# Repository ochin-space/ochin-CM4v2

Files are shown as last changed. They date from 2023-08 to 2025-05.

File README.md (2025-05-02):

ochin_CM4
# ochin_CM4 v2.0.1
The öchìn CM4 it’s a tiny carrier board for the Raspberry Pi Compute Module  It is designed for applications where a powerful machine with low consumption and small dimensions is required. The small form factor makes it interesting for all those applications where the space available is not much and containing the weight is important, such as in robotics, home automation and IOT.

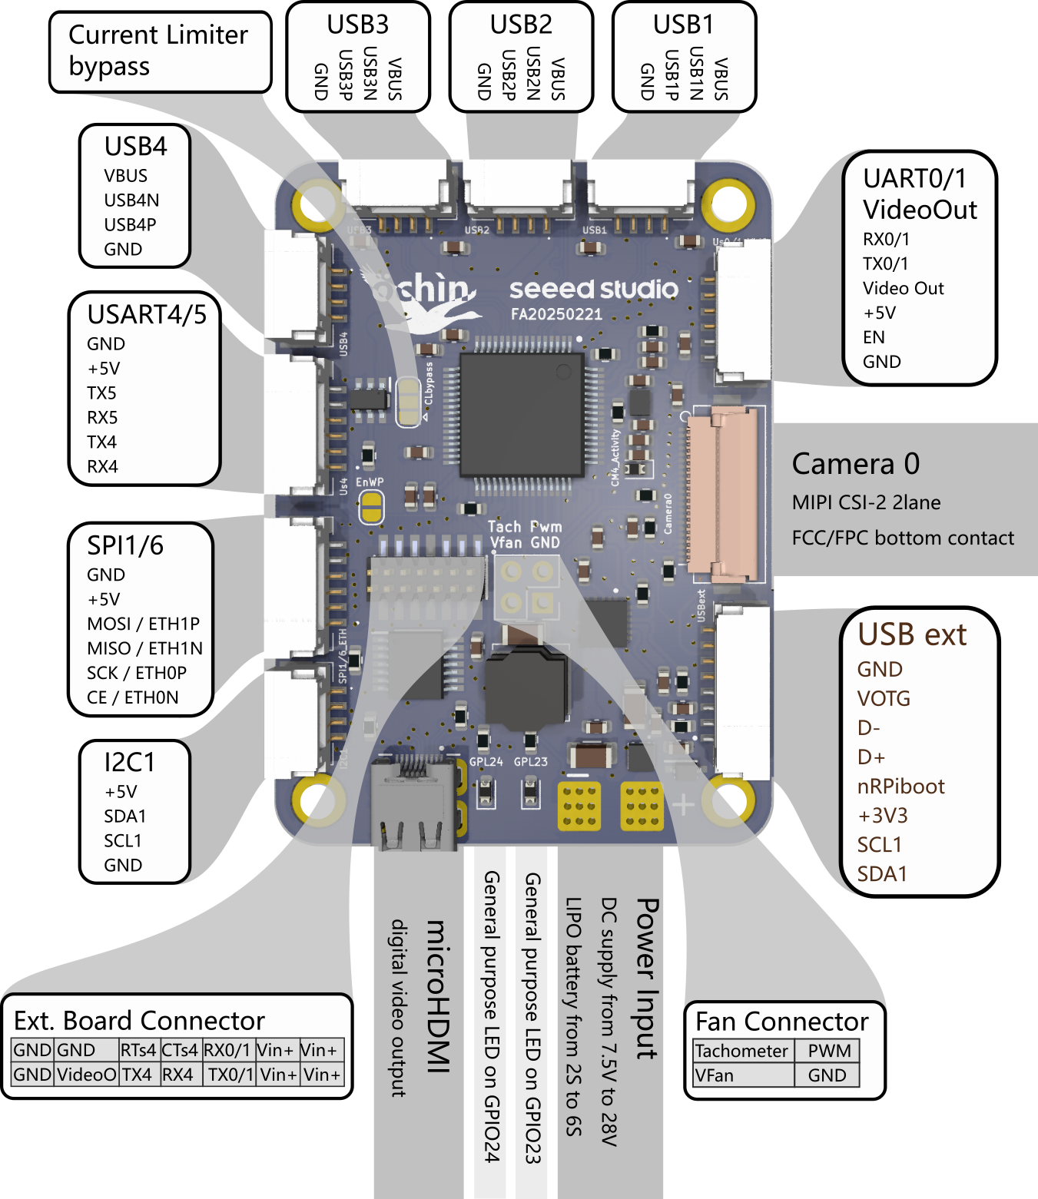
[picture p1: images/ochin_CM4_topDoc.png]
ochin_CM4


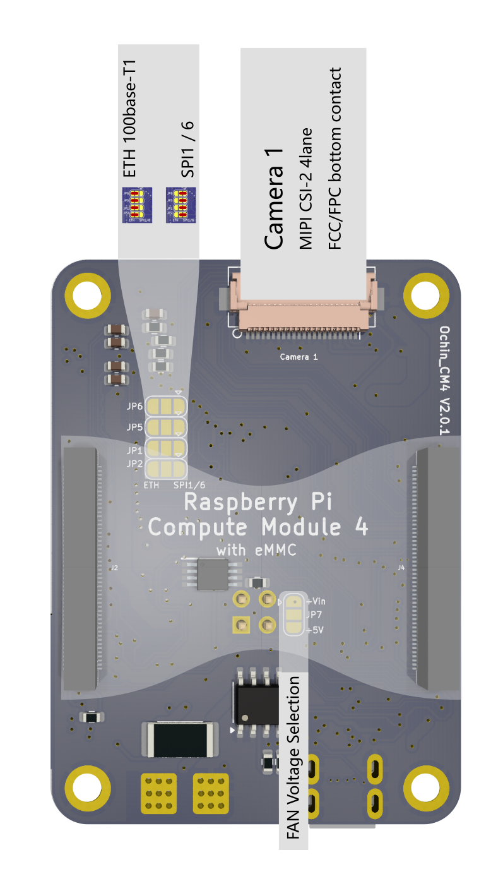
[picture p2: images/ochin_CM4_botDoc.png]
ochin_CM4 back


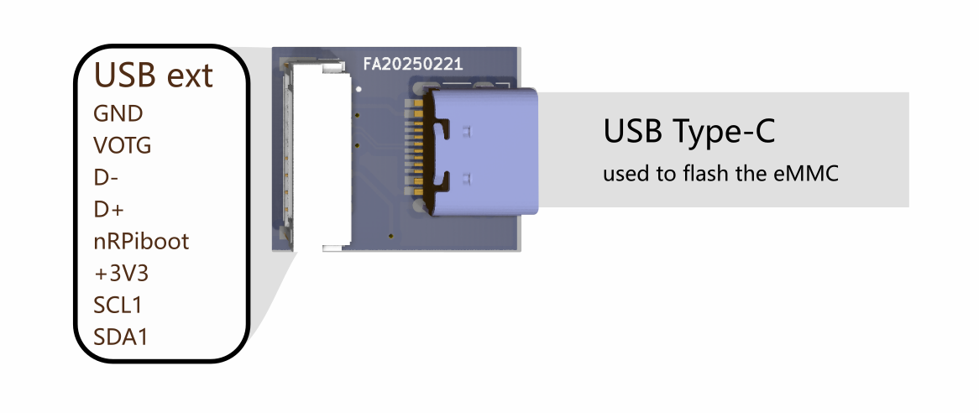
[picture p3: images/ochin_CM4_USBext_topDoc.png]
ochin_CM4extUSB


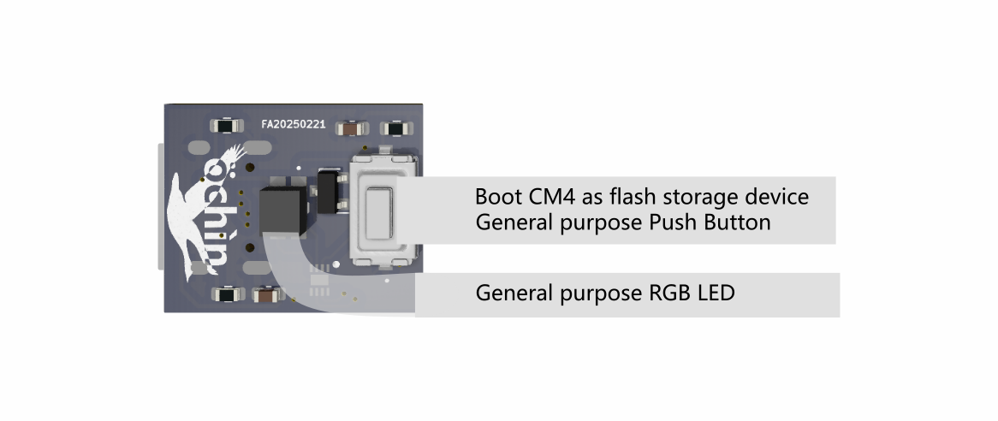
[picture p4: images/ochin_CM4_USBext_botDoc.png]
ochin_CM4extUSB


The board is compatible with all Raspberry Pi CM4 modules equipped with eMMC. Depending on your needs, you can select a CM4 module with an SDRAM starting from 1GB up to 8GB and the eMMC from 8GB up to 32GB, with or without the Wi-Fi/BT module.

Key features of the Raspberry Pi CM4 available on öchìn are as follows:
* Broadcom BCM2711, Quad core Cortex-A72 (ARM v8) 64-bit SoC @ 1.5GHz
* Small Footprint 55mm × 40mm × 4.7mm module
* H.265 (HEVC) (up to 4Kp60 decode), H.264 (up to 1080p60 decode, 1080p30 encode)
* OpenGL ES 3.0 graphics
* Options for 1GB, 2GB, 4GB or 8GB LPDDR4-3200 SDRAM with ECC
* Options for 8GB, 16GB, or 32GB eMMC Flash
o Peak eMMC bandwidth 100MBytes/s
o 2.4 GHz, 5.0 GHz IEEE 802.11 b/g/n/ac wireless
o Bluetooth 5.0, BLE
o On board electronic switch to select between PCB trace or external antenna
* 1×USB 2.0 port (highspeed)

The öchìn CM4v2 board provides the following interfaces:

*	4x USB 2.0 480Mbps (4x SM04B-GHS-TB(LF)(SN) connectors)
*	1x USB Type-C (for flashing eMMC)
*	2x CSI camera (2x FH12-22S-0.5SH (55) connectors)
*	I2C1 (SM04B-GHS-TB(LF)(SN) connector)
*	SPI1 / 6 (SM06B-GHS-TB(LF)(SN) connector)
*	UART0 / 1 + Video Out (SM06B-GHS-TB(LF)(SN) connector)
*	UART4 / UART5 (SM06B-GHS-TB(LF)(SN) connector)
*	1x Ethernet transformerless 100Base-T
*	1x microHDMI
*	2x general purpose LEDs
*	1x RGB LED on external tiny board
*	1x general purpose button on external tiny board

The ochin_CM4v2 card introduces several new features compared to v1, some of which are very interesting and which considerably broaden its range of use. 

Below is a table in which it is possible to see which are the new fetures and which has been removed.

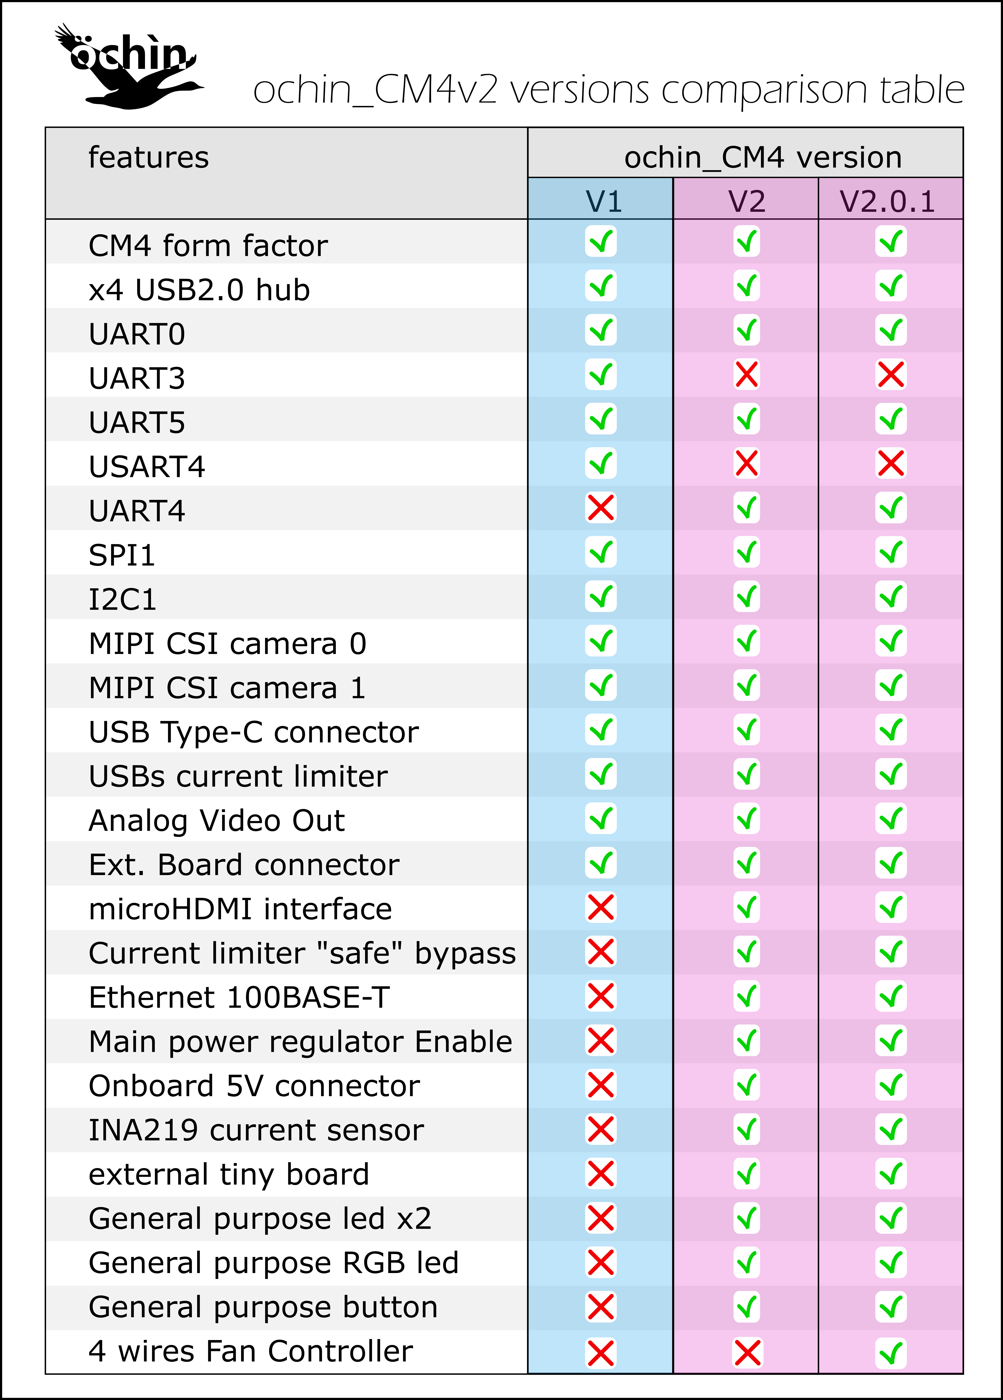
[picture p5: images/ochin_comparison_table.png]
ochin_CM4 comparison table


In this repository you can find the [manual](öchìnCM4v2-Manual.pdf) of the board, a quick start guide for flashing the CM4 module and a guide with some tips on how to make the connections to the ochin board. 

It is important to read them both before turning on the ochin_CM4v2 board, to know its characteristics and above all the sequence in which the signals are present on the connectors.

# Where to buy the ochin_CM4 boards
The ochin_CM4 boards are manufactured and sold by Seeedstudio. You can purchase ochin_CM4 boards from Seeedstudio's marketplace, https://www.seeedstudio.com or from Seeedstudio's business partners (Digikey, Mouser, RS components and many others).

# License Notice for This GitHub Repository

This GitHub repository contains various resources that are subject to specific licenses. Please note the following information regarding the applicable licenses:

* Documentation, Manuals, PDF Schematics, scripts and Other Textual Content: All textual documents present in this repository, including manuals, schematics, and documentation, are released under the GNU Free Documentation License (GFDL).

* Hardware (KiCad Sources, Gerber Files, Assembly Files, etc.): The hardware-related items, including but not limited to KiCad sources, Gerber files, and assembly files, are subject to a proprietary license. This means that these resources are not released as open source and their use is governed by the terms specified in the accompanying documentation or separate terms of use provided.

Please respect the conditions of both licenses when using and distributing the materials in this repository.

For any questions or clarifications regarding the [LICENSE](LICENSE), feel free to contact us.

# Important!!!

Print and use the extractor for the CM4 module if you don't want to break the mezzanines, you can find the [ochin_mount-extractor.stl](3d/CoversTurretsAndExtractors/ochin_mount-extractor.stl) in the "3d/CoversTurretsAndExtractors" section of this repository.

Take a look at the [öchìnCM4v2-WiringAndSuggestions.pdf](öchìnCM4v2-WiringAndSuggestions.pdf) before power the board on, it may save your time and your devices.

Never trust the color code of the GHS cables, the sequence in which commercial GHS cables are assembled is often random and does not reflect the sequence of the signals present in the connectors of the ochin_CM4 board.

Please refer to the file [öchìnCM4v2-HW-bugs.pdf](öchìnCM4v2-HW-bugs.pdf) for details regarding known issues on the board and the respective version in which they were resolved

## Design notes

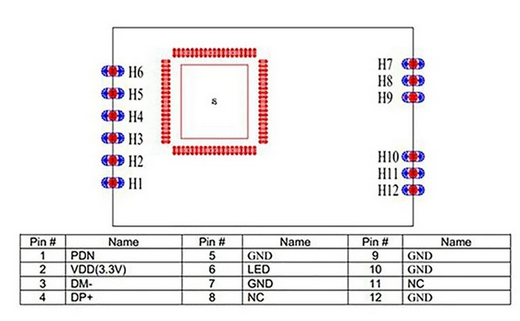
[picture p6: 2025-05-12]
3d/ochin VRX goggleBox/kicad RTL8812AU module pwr/RTL8812AU_pinout.png

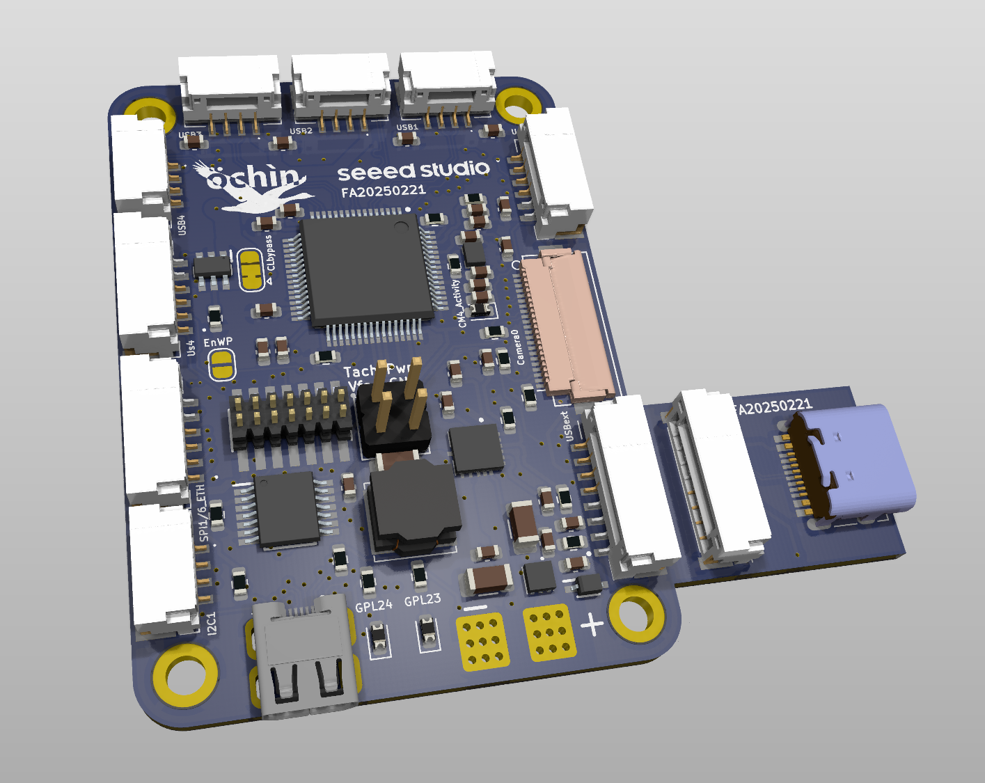
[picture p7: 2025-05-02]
images/Ochin_CM4_main_top_back.png

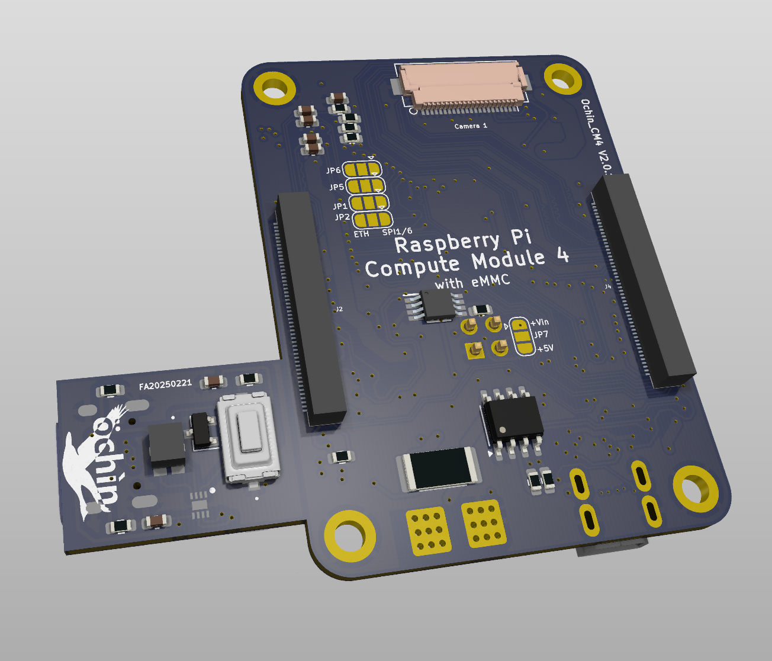
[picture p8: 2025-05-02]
images/Ochin_CM4_main_bot.png

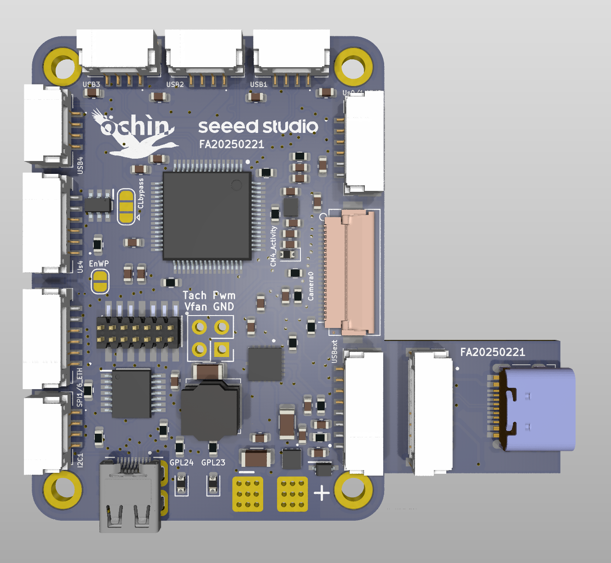
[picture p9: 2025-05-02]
images/Ochin_CM4_top_main.png

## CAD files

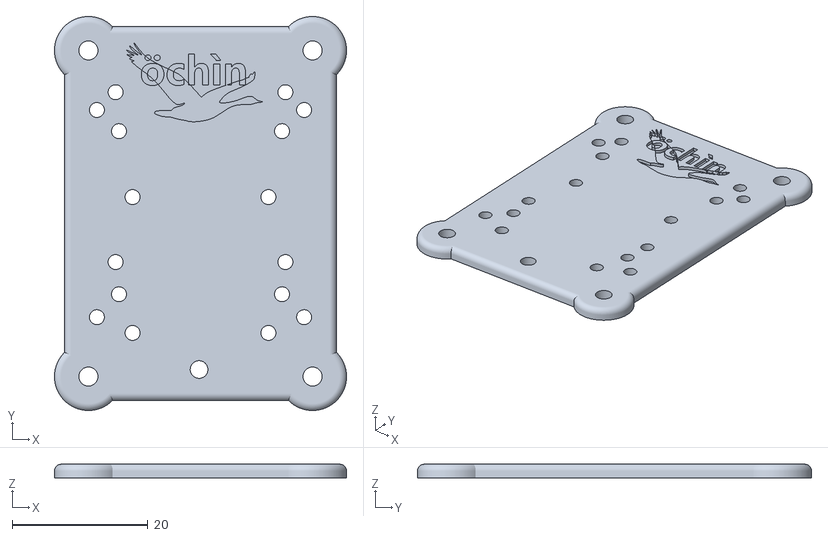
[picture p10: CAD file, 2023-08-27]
3d/CoversTurretsAndExtractors/ochin_mount-topCover.stl
43.0 x 58.0 x 2.00

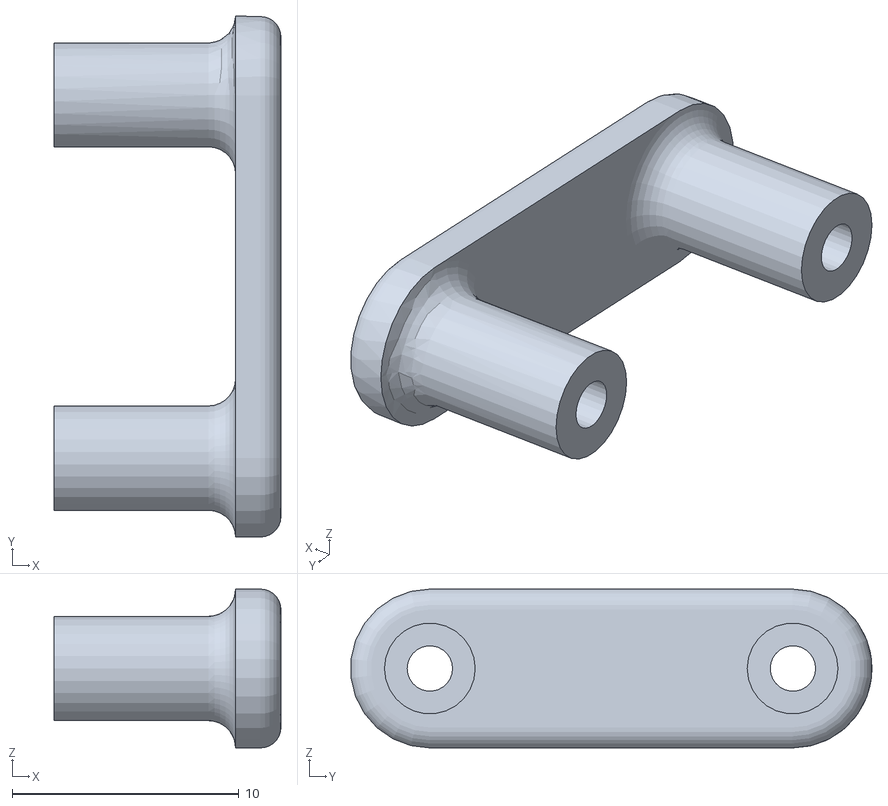
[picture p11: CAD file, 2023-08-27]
3d/EasyStar ii_IMX219_mount/EasyStar_camera_mount_bridge.stl
10.0 x 23.0 x 7.00

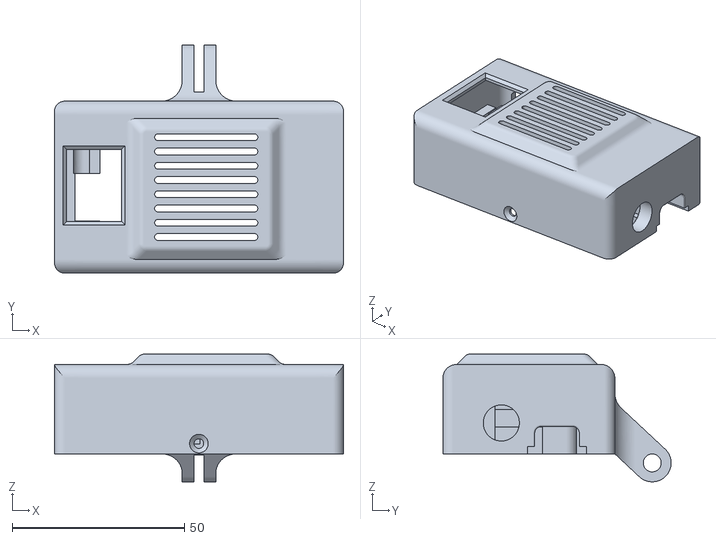
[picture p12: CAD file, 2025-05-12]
3d/ochin VRX goggleBox/Top.stl
84.0 x 66.4 x 37.1

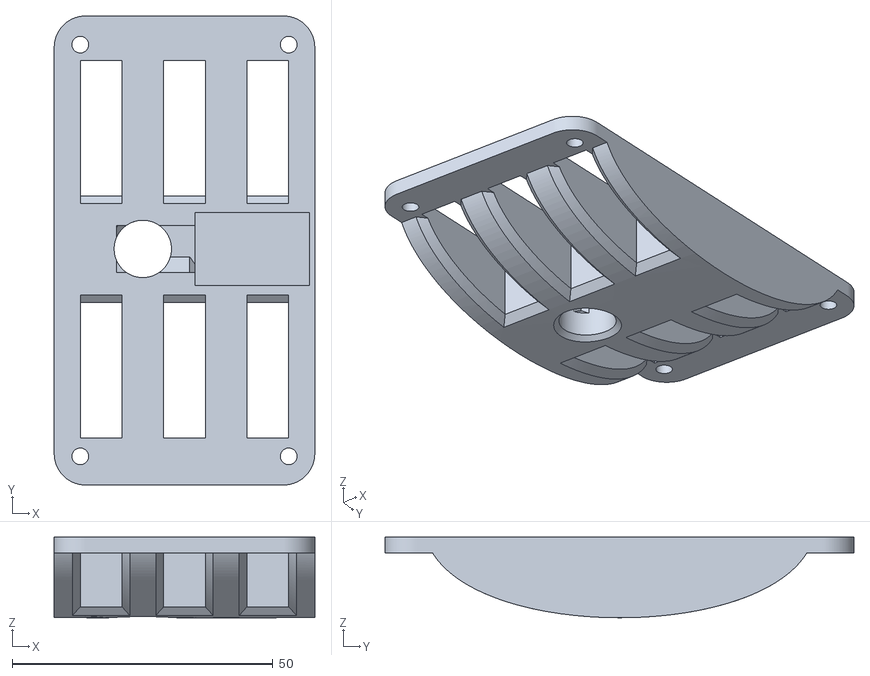
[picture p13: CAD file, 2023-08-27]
3d/ochin_cm4_plate_mount/ochin_cover+camera.stl
50.0 x 90.0 x 15.5

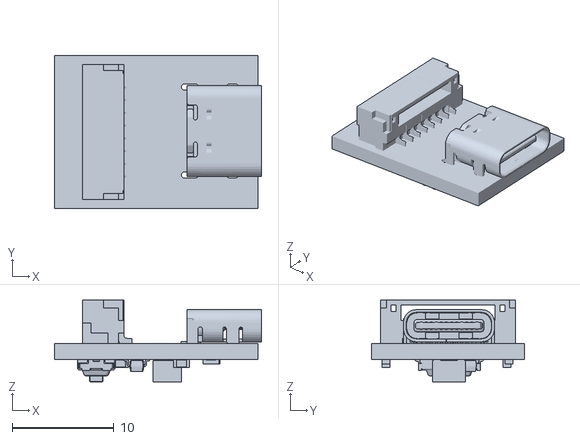
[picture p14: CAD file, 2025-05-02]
3d/ochin_CM4v2_0_1/Ochin_CM4_V2_0_1_ext.stl
20.3 x 15.0 x 8.04

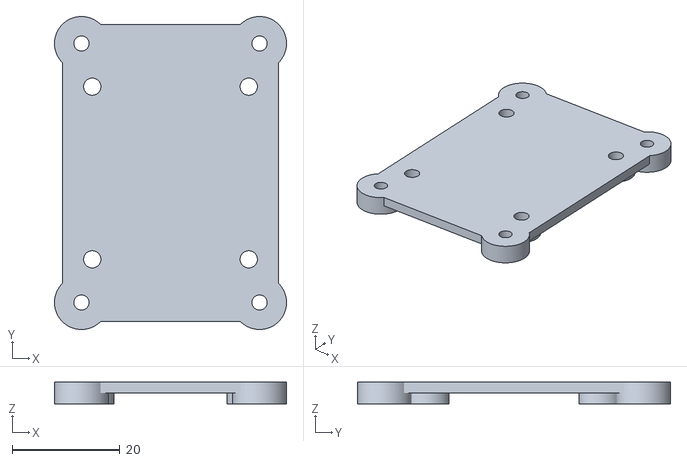
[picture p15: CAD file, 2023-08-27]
3d/CoversTurretsAndExtractors/ochin_mount-botCover.stl
43.0 x 58.0 x 4.00

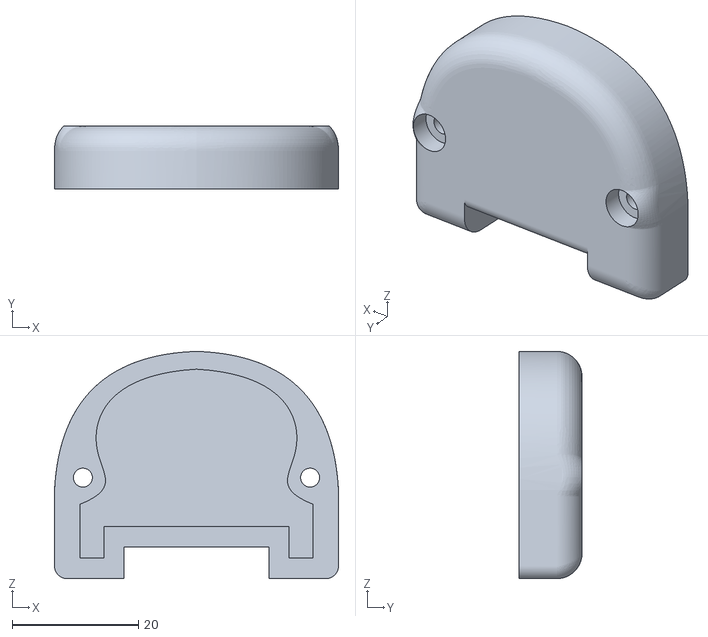
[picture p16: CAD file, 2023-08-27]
3d/EasyStar ii_IMX219_mount/EasyStar_camera_mount_cap.stl
45.0 x 10.0 x 36.0

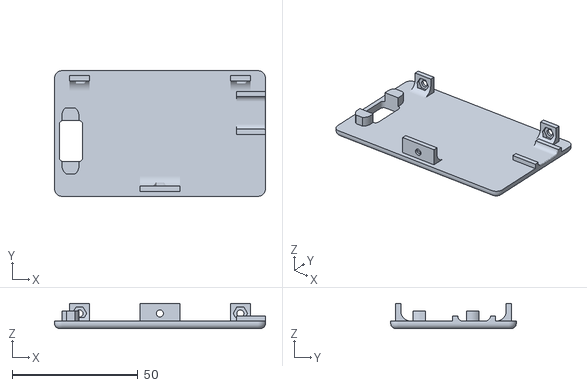
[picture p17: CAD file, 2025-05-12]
3d/ochin VRX goggleBox/Bot.stl
84.0 x 50.0 x 10.0

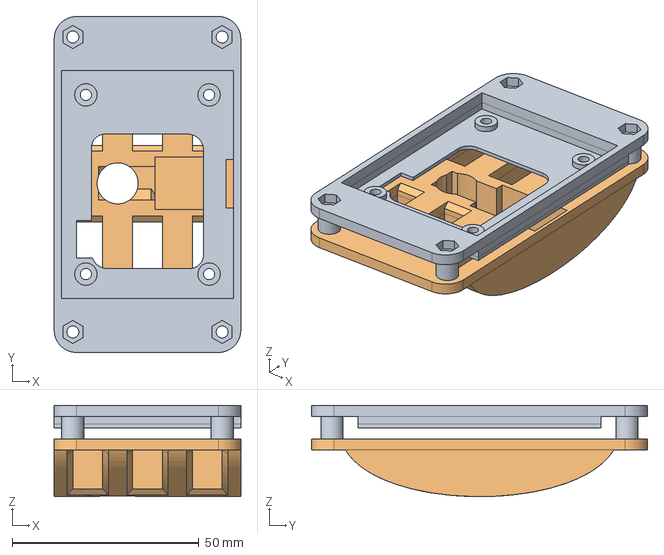
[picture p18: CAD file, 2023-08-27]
3d/ochin_cm4_plate_mount/ochin_plate+cover.FCStd
50.0 x 90.0 x 24.5 mm
ochin mount
cover+camera

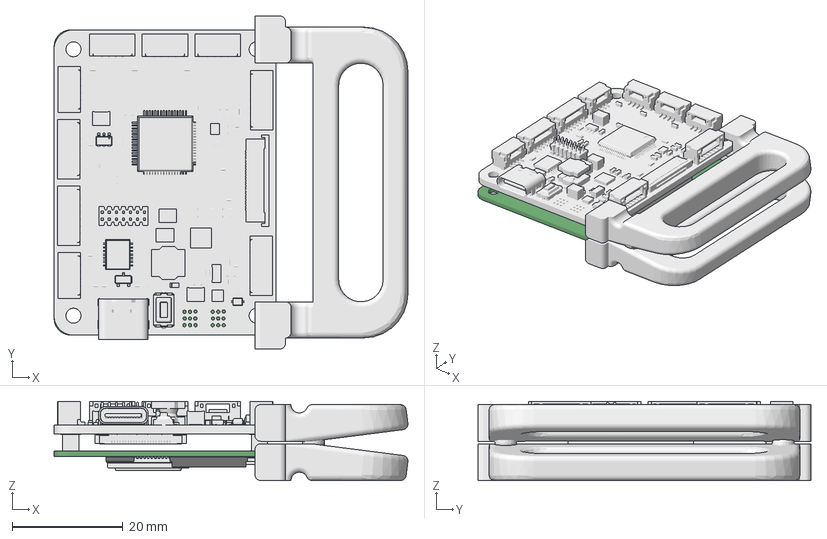
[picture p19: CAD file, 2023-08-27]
3d/CoversTurretsAndExtractors/ochin_mount.FCStd
63.8 x 60.0 x 14.3 mm
PCB
BROADCOM_BCM2711
CONNDF40C-100DP-04V
CONNDF40C-100DP-04V (1)
MAXLINEAR_MXL7704-R
RM0_FOOTPRINT_V2
SAMSUNG_KLM4G1YE4C-B00X
SDRAM-LPDDR4-X32-D2-BGA200
extractor
extractor2
ochin_CM4-Ochin

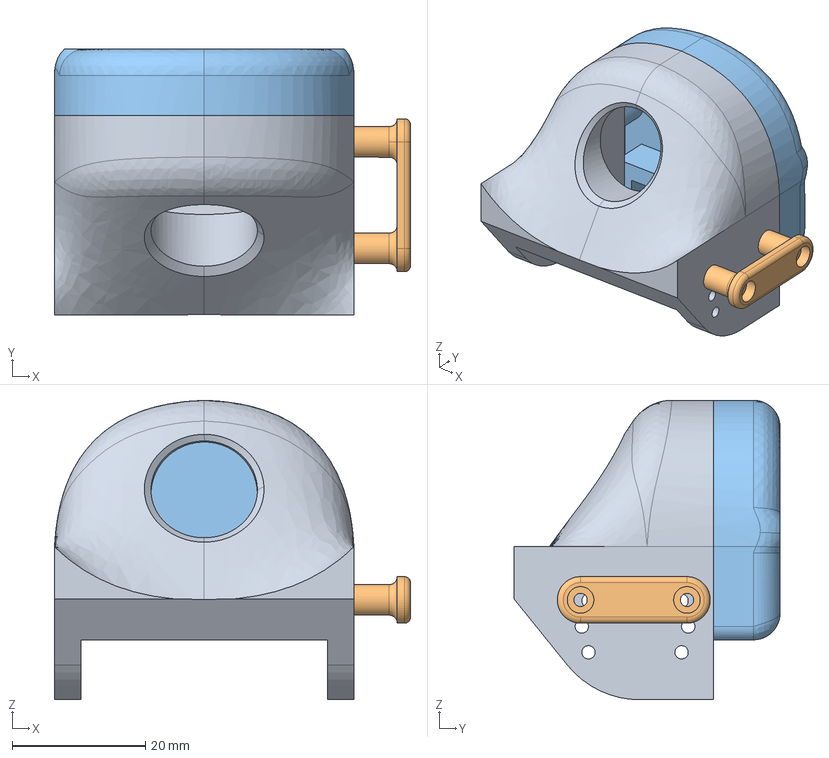
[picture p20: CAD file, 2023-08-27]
3d/EasyStar ii_IMX219_mount/EasyStar_camera_mount.FCStd
53.5 x 40.0 x 45.0 mm
supportoCam
staffa
coperchio

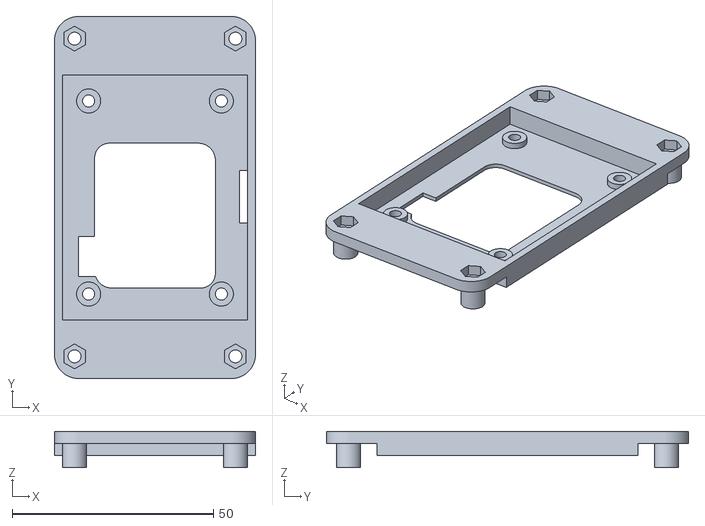
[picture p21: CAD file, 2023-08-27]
3d/ochin_cm4_plate_mount/ochin_plate.stl
50.0 x 90.0 x 9.00

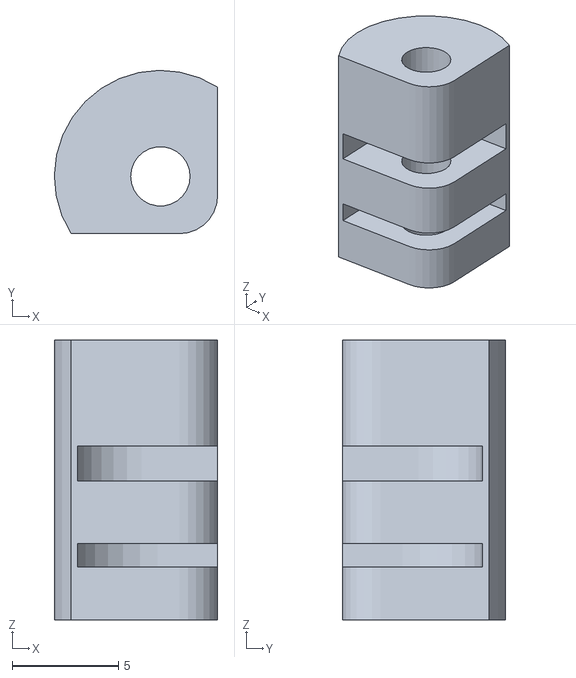
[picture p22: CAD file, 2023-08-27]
3d/CoversTurretsAndExtractors/ochin_mount-turret.stl
7.70 x 7.70 x 13.2

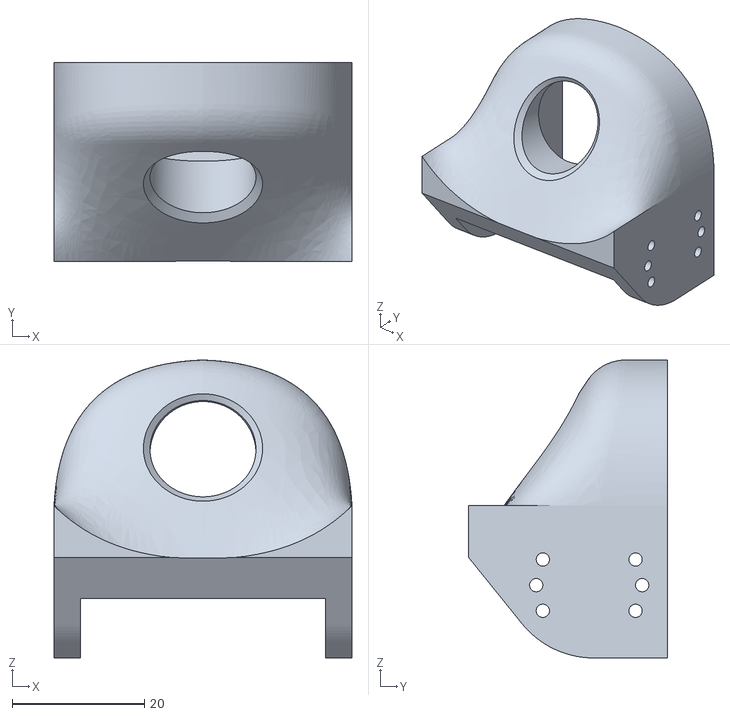
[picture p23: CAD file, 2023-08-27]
3d/EasyStar ii_IMX219_mount/EasyStar_camera_mount_front.stl
45.0 x 30.0 x 45.0

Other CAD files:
3d/CoversTurretsAndExtractors/ochin_mount-extractor.stl
3d/ochin VRX goggleBox/ochin_goggleBox v18.f3d

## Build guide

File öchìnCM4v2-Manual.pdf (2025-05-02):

öchin CM4v2 carrier board manual v0.2 | 9 agosto 2024

## Introduction

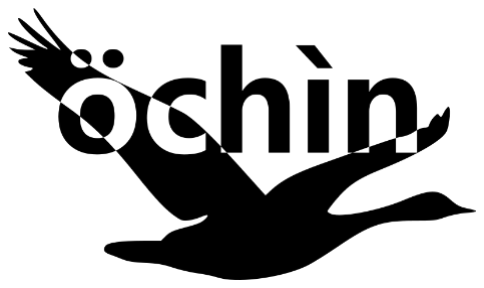
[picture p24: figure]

The öchìn CM4v2 it’s a tiny carrier board for the Raspberry Pi Compute Module 4. It is designed for applications where a powerful machine with low consumption and small dimensions is required. The small form factor makes it interesting for all those applications where the space available is not much and containing the weight is important, such as in robotics, home automation and IOT.

The board is compatible with all Raspberry Pi CM4 modules equipped with eMMC. Depending on your needs, you can select a CM4 module with an SDRAM starting from 1GB up to 8GB and the eMMC from 8GB up to 32GB, with or without the Wi-Fi / BT4 connection.

Key features of the Raspberry Pi CM4 compatible with öchìn are as follows:

- Broadcom BCM2711, Quad core Cortex-A72 (ARM v8) 64-bit SoC @ 1.5GHz
- Small Footprint 55mm × 40mm × 4.7mm module
- H.265 (HEVC) (up to 4Kp60 decode), H.264 (up to 1080p60 decode, 1080p30 encode)
- OpenGL ES 3.0 graphics
- Options for 1GB, 2GB, 4GB or 8GB LPDDR4-3200 SDRAM with ECC
- Options for 8GB, 16GB, or 32GB eMMC Flash
- Peak eMMC bandwidth 100MBytes/s
- 2.4 GHz, 5.0 GHz IEEE 802.11 b/g/n/ac wireless
- Bluetooth 5.0, BLE
- On board electronic switch to select between PCB trace or external antenna
- 1×USB 2.0 port (highspeed)
- MIPI CSI-2:
- 1×2-lane MIPI CSI camera port, 1×4-lane MIPI CSI camera port
- 1×USART, 3×UART, 1×I2C port, 1×SPI port, Analog Video Output

Design

The board has the same dimensions as the RPi CM4 module, 55mm x 40mm with rounded corners.
Several interfaces like USARTs, USBs are addressable bye the SM06B-GHS and SM04B-GHS connectors, available on the sides of the board. Two FCC/FPC connector are available to connect two MIPI CSI-2 cameras. The front camera is the “camera 1” which is a MIPI CSI-2 4lane camera. The side camera is the “camera 0” which is a MIPI CSI-2 2lane camera. The two FCC/FPC connectors have contacts on the bottom, the interface is the same used on the Raspberry Pi Zero.
On top of the board there is a 14x1.27mm connector, that could be used to connect a custom board on top, replacing the top PCB cover.
On the bottom of the öchìn carrier board there are the DF40HC(3.0)-100DS-0.4v mating connectors for the CM4 module.

## Applications

The powerful Quad core Cortex-A72 CPU and GPU, the big RAM size and the CODECs and Graphic Accelerators available on the CM4 makes the system very interesting for a huge number of applications. Are suitable all the applications related to audio / video manipulation and streaming, neural networks, machine learning, computer vision, etc.

There are several communication interfaces available on board that enables to connect the öchìn to external hardware to connect to the lower abstraction layers, closer to the physical world.

An example of use could be a drone, where a flight controller board sense the physical references and control the actuators and motors to guarantee the stability of the flight. It could handle the stability of the vehicle, collect the data from the sensors and from the remote control and send the telemetry data back to the ground station. This is a very common structure nowadays for a UAS. The öchìn board could be used to add a wide range of functionality to the system.

The öchìn could handles up two MIPI cameras and others connected to the USB interfaces. Other sensors could also be added to the öchìn using the UART, SPI, I2C interfaces. All those data could be processed by several threads running on the CM4.

The software infrastructure available within the CM4 enables to code with C/C++, python, MATLAB, and several other languages. There is also a wide number of frameworks that can be used to develop algorithms with Deep Learning, Neural Networks or Computer Vision technique, such as OpenCV, Caffe, PyTorch, TensorFlow etc. The öchìn board also provide the analog video output from the CM4. It means that it’s possible to create a video output from the whole set of data, including images and its elaboration, to transmit like a common analog video out. This is very convenient because it gives the chance to see the output of the processing in real time without taking care of creating a digital wireless bridge.

This is only an example, a similar structure could be though for rovers, submarines, airplanes, and robots in general. Of course, the öchìn board it’s very interesting for the IOT world also, where the size and weight is important. In this scenario, the AI is relevant and the tendency to miniaturize IOT devices and make them increasingly intelligent requires adequate hardware.

## Hardware interfaces

The öchìn CM4v2 board provides the following interfaces on the side’s connectors:

- 4x USB 2.0 480Mbps (4x SM04B-GHS-TB(LF)(SN) connectors)
- 1x USB Type-C (for flashing eMMC)
- 2x CSI camera (2x FH12-22S-0.5SH (55) connectors)
- I2C1 (SM04B-GHS-TB(LF)(SN) connector)
- SPI1 / 6 (SM06B-GHS-TB(LF)(SN) connector)
- UART0 / 1 + Video Out (SM06B-GHS-TB(LF)(SN) connector)
- UART4 / UART5 (SM06B-GHS-TB(LF)(SN) connector)
- 1x Ethernet transformerless 100Base-T
- 1x microHDMI
- 2x general purpose LEDs
- 1x RGB LED on external tiny board
- 1x general purpose button on external tiny board
- 1x 4-Wire Fan controller (pwm, tacho, supply voltage selectable, Vin or 5V)

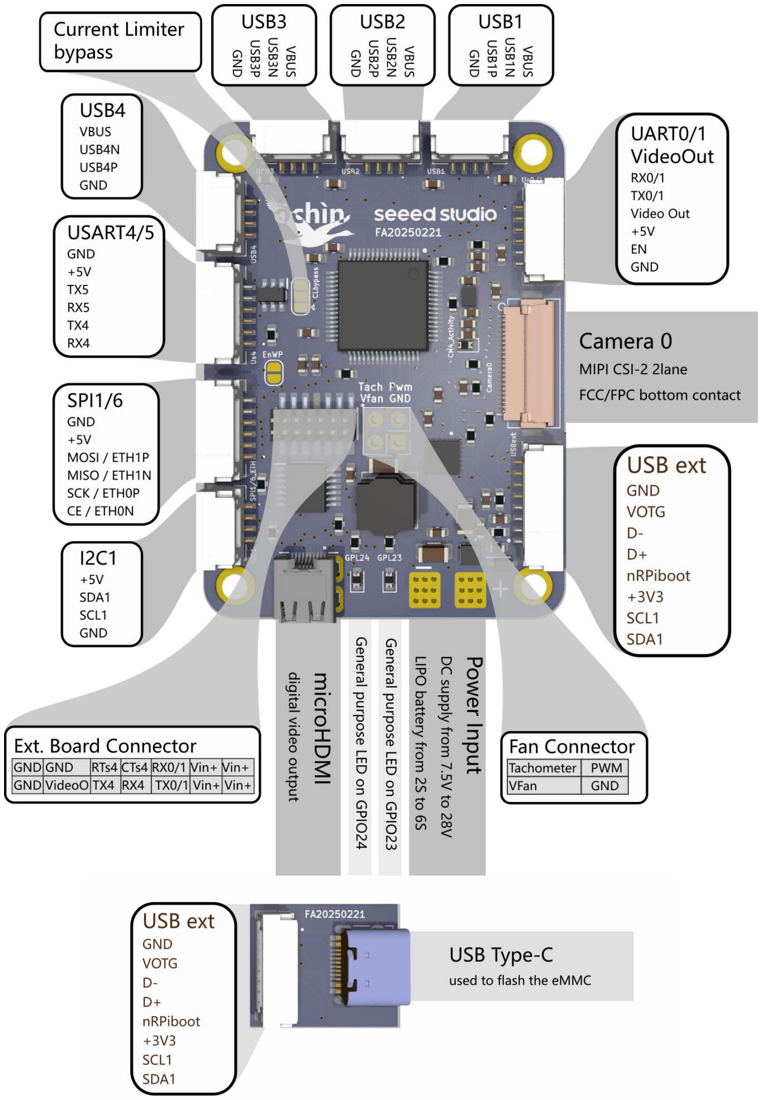
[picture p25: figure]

Top view

Bot view

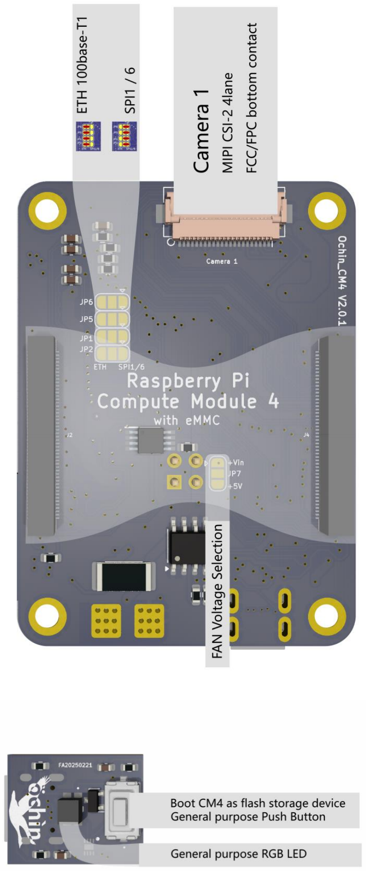
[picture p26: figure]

## USB

The Raspberry Pi CM4 module is equipped with a single USB2.0 interface. In order to connect multiple USB devices to the CM4 module, the ochin_CM4v2 board is equipped with a 4xUSB2.0 HUB. The four USB ports are accessible via the four SM04B-GHS connectors. We recommend that you read the document 'Wiring and Suggestion' to make the connections correctly.

It should be noted that the same USB port on the CM4 is also shared with the USB Type-C connector, which is needed to write the OS in flash. This switching occurs when connecting USB Type-C to a computer. In fact, the VBus provided by the computer switches the USB from the HUB to the Type-C port to allow the module to be flashed.

It is therefore important to bear in mind that none of the 4 USB ports will work as long as the ochin board is connected via a USB Type-C cable to a computer.

## SPI1/Ethernet

The connector, named SPI1/6, can be used to connect to either the SPI1/6 or the Ethernet port. In order to allow either connection, there are four smd switches (normally open) on the back of the ochin_CM4v2 board, which must be soldered appropriately.

In order to use the connector as SPI1/6, it is necessary to solder the jumpers between the central pad and the pad on the right (indicated by the word SPI1/6) of JP6,5,1,2 as shown in the following figure:

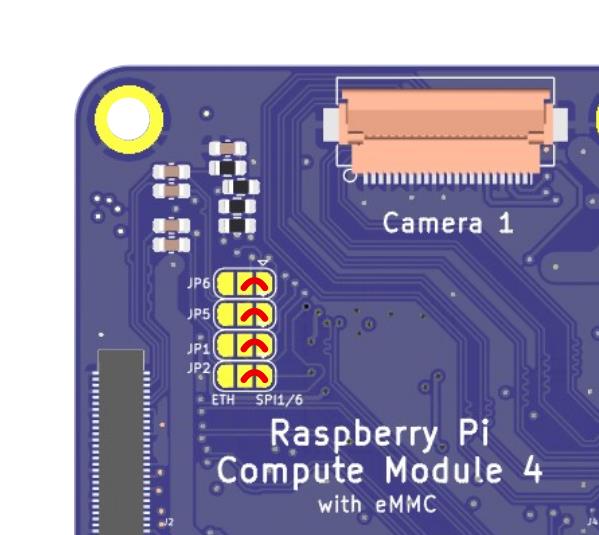
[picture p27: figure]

The order of the signals on the SPI1/6 connector is as follows

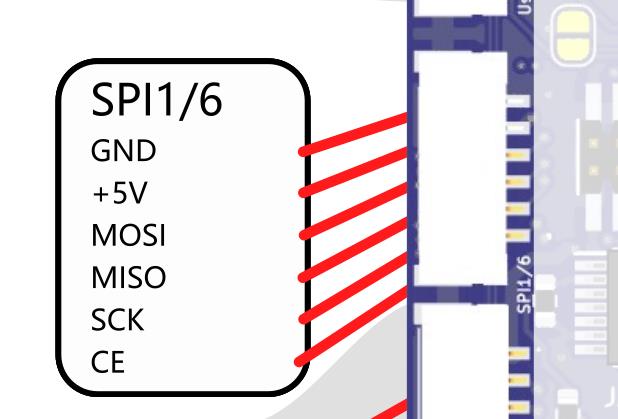
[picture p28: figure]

In the case of connecting to the Ethernet port of the RPI CM4, the smd switches JP6,5,1,2 should be soldered as follows:

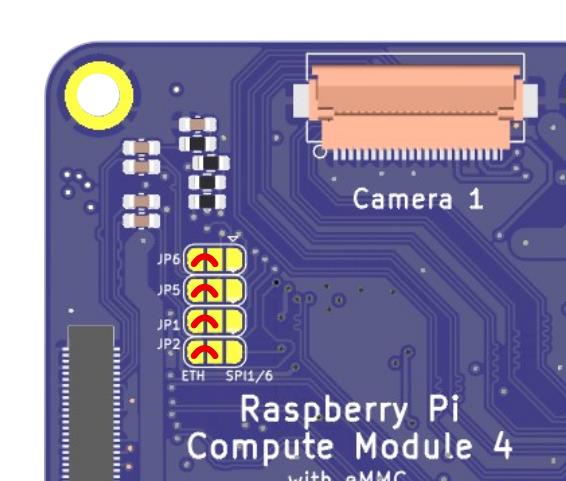
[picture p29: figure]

In this case, the order of the signals on the SPI1/6 connector will be as follows:

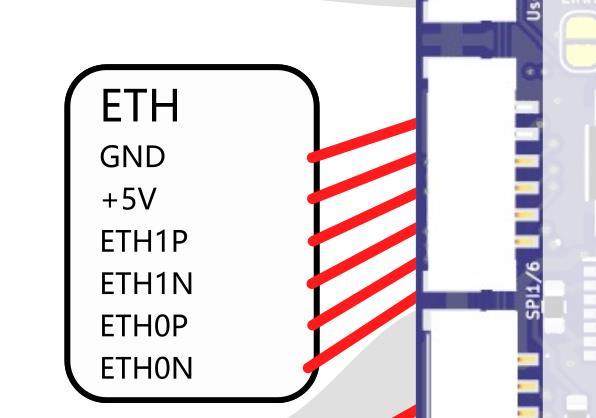
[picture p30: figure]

An important note must be made regarding the Ethernet connection. In order to allow Ethernet connectivity and without affecting the size of the ochin_CM4v2 board, it was decided to adopt a transformerless configuration, like the one adopted and described by Texas Instruments in Application Note AN-1519 for their DP83848 Ethernet devices. It is therefore advisable to study and understand the AP-1519 before deciding to use the Ethernet port in a transformerless configuration.

The following image represents the connection diagram for connecting to the ochin_CM4v2 using a standard RJ45 cable:

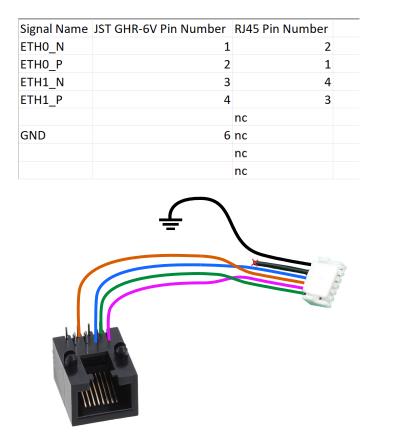
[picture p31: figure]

## The Fan Controller

he Ochin board features an integrated EMC2301 fan controller connected to the I²C1

bus. To support external fans operating at 5V, 12V, or higher voltages, a normally open

SMD switch is provided on the bottom side of the board and must be soldered manually

to enable fan power routing.

By default, if the EMC2301 is not actively configured via software, the fan will operate

at maximum speed. When properly controlled, the EMC2301 allows for PWM-based

speed regulation of both 3-wire (open-loop) and 4-wire (tacho-sensed) fans.

A basic Python test script is included in the documentation to verify functionality. For

accurate integration and usage, please refer to the EMC2301 datasheet.

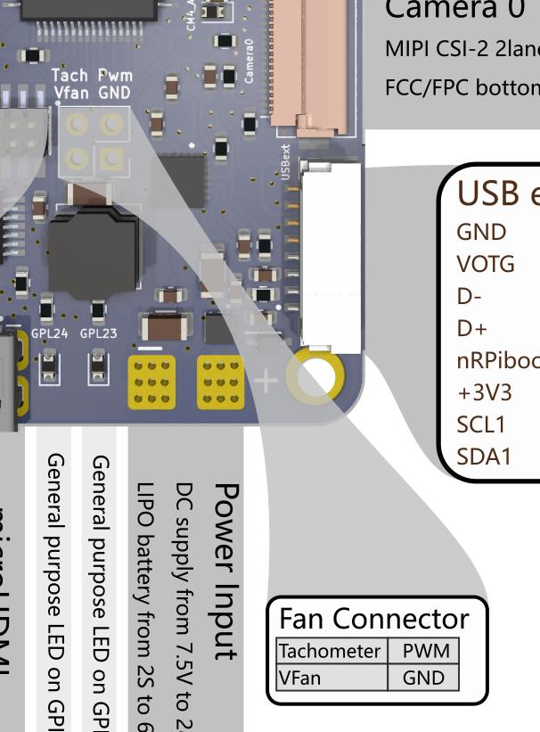
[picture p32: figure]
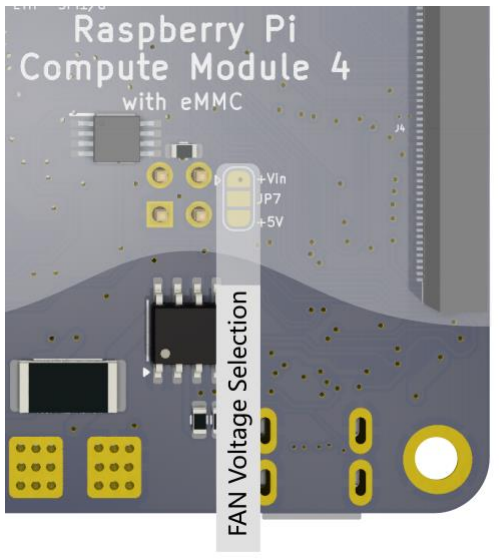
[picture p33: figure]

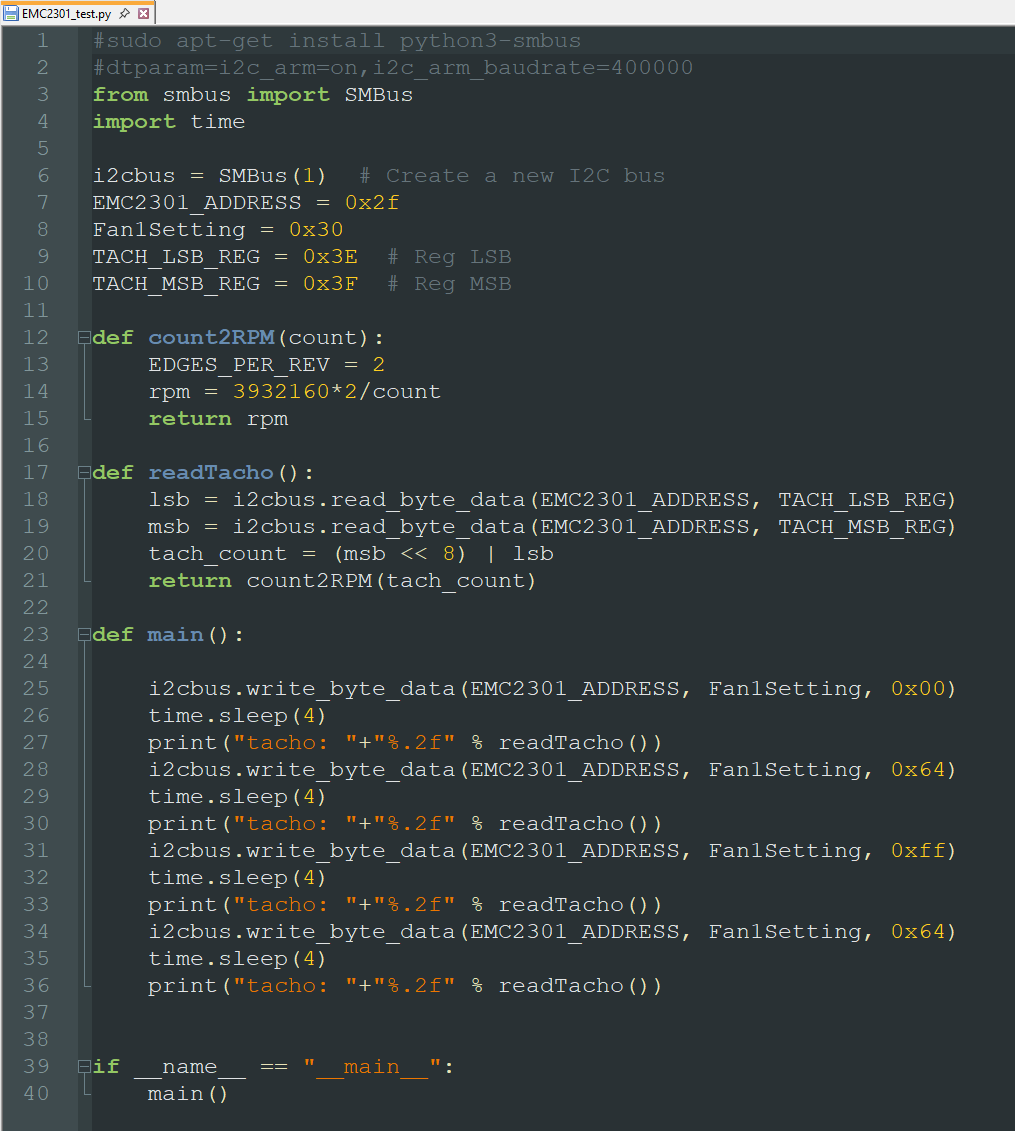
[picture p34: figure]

## The Current Limiter

The IC4 - AP22615AWU-7 is a single-channel current-limited high-side
power switch with output OVP optimized for USB and other hot-swap
applications. On the ochin_CM4 board, the current threshold of the AP22615AWU-7 is set to 3A. If the IC4 it’s triggered, it will cut the VBUS on the USBs to keep the CM4 supplied while an overcurrent condition happens. There are four possible condition that triggers the current limiter:
(from the AP22615 datasheet Document number: DS41022 Rev. 5 – 2):

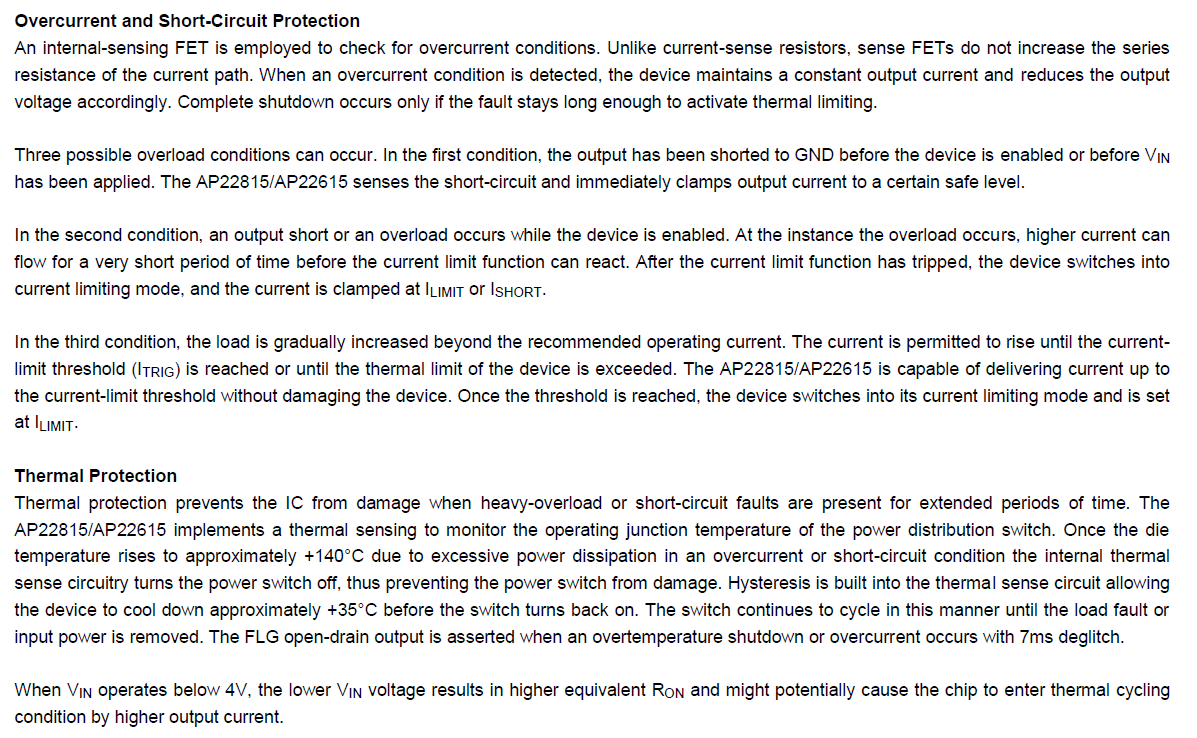
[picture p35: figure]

In case more current is needed on the USBs, it is necessary to short JP4 (CLbypass).

Before shorting JP4, it is important to cut the "normally closed" trace, between pads 1

and 2 of JP4 (pad 1 is the one indicated by the triangular marker). This is done by using

a sharp blade and making sure that you only cut the connection between the two pads,

and if necessary, test it with a multimeter. If the current limiter is bypassed, the USB

power supply is connected directly to the output of the +5V switching regulator, the

same one that powers the CM4. The power supply can provide up to 8A, leaving 2A for

the CM4 (the manual says 1.4A but it is best to be cautious); 6A remains available for

USB and external peripherals. That said, before removing the limiter, it is important to know how much current the external peripherals will draw, so leave current for the CM4,

otherwise it will reboot.

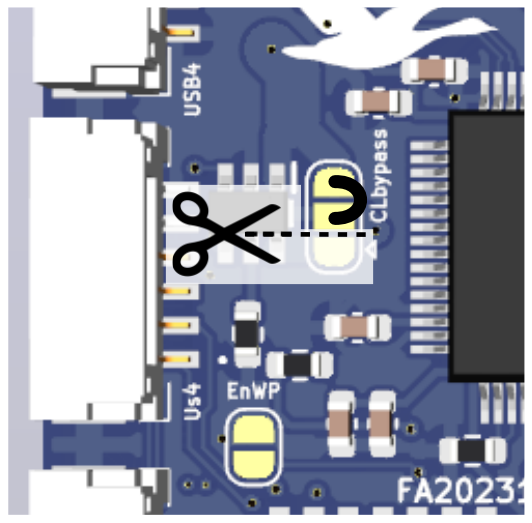
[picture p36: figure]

## eMMC write protection

To write protect the eMMC it’s necessary to short the jumper named EnWp:

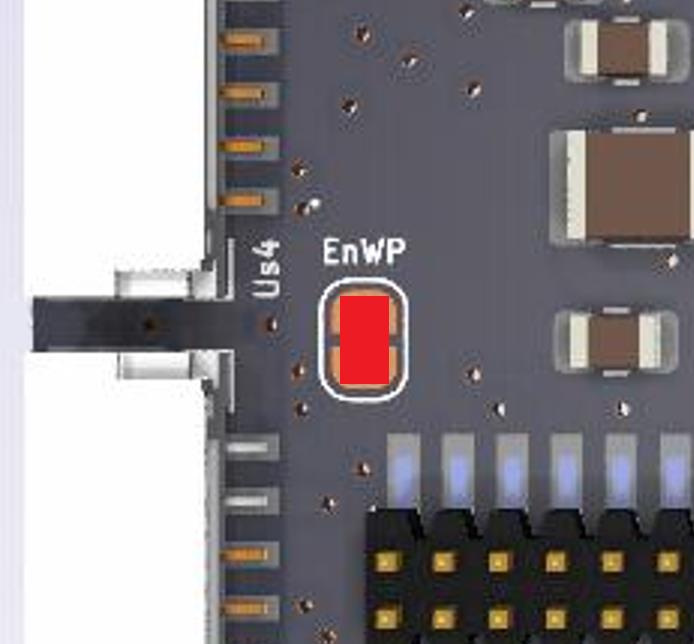
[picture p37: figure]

## The current sensor INA219

In order to measure the current drawn by the ochin_CM4v2 board and all its peripherals, it was equipped with an INA219 current sensor. The chip is located on the bottom of the pcb and works by measuring the potential drop at the ends of a shunt resistor. The chip is connected to the CM4 module via the I2C1 bus (addr. 0x40) by means of which it is possible to read the input voltage measurement, the shunt voltage and after calibration of the chip also power and current drawn. To calculate the current from the shunt voltage, it is necessary to know the shunt resistance, which in the case of the ochin_CM4v2 is 100mOhms. For details on how to read, write and calibrate the INA219 chip, it is necessary to study its datasheet, provided by Texas Instruments.

## The LEDs GPL23 and GPL24

The anodes of the two LEDs GPL23 and GPL24 are connected to the GPIO23 and

GPIO24 pins of the Raspberry Pi CM4, respectively. They can be used for debugging

purposes or for status signalling. It is possible to manage the two LEDs by means of the

Raspberry Pi's GPIO management libraries.

Below is an example of managing the two LEDs using a script in Python:

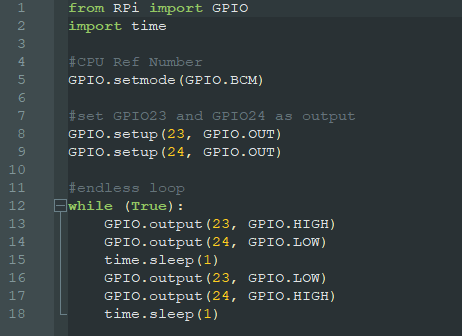
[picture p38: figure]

## The S1 button

The S1 button on the small external board has two functions. The first is to put the

CM4 module in 'flash mode' to allow the user to access the flash on the module itself.

This procedure is explained in more detail in the "Software Configuration" section. If

the CM4 module is started up in normal mode, the S1 button also performs the

function of a "user button". This is possible because in addition to being connected to

the "nRPIBOOT" pin, it is also connected to the GPIO4 pin. The button can therefore

be used during normal operation to interact with the sw running on the CM4 module.

To know the status of the button, i.e. whether it is pressed or not, simply configure the

GPIO4 as an input and monitor its status. Since GPIO4 is "active low", it is to be

expected that it will go to "false" if S1 is pressed and be "true" the rest of the time.

Below is an example of managing the two LEDs using a script in Python:

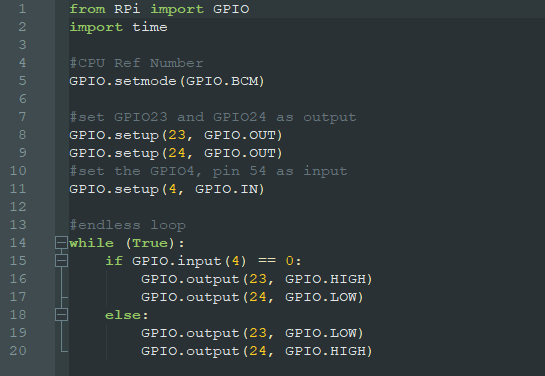
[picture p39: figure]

## The RGB led

On the external board, next to the S1 button is an RGB LED. This LED is present for the

purpose of being used at will by the user, to communicate any information by means of

all possible colour tones, intensities and flashes. Management of the RGB LED is

entrusted to a chip called KTD2026, which is connected to the CM4 module via the I2C1

interface.

Using the I2C libraries, it is possible to configure the chip to vary the intensity of each

of the three basic colours and their respective transitions. For more precise and detailed

information on the handling of the chip, it is necessary to study the datasheet of the

KTD2026, available on the website of the manufacturer, Kinetic Technologies

(https://www.kinet-ic.com).

Below is an example of managing the two LEDs using a script in Python:

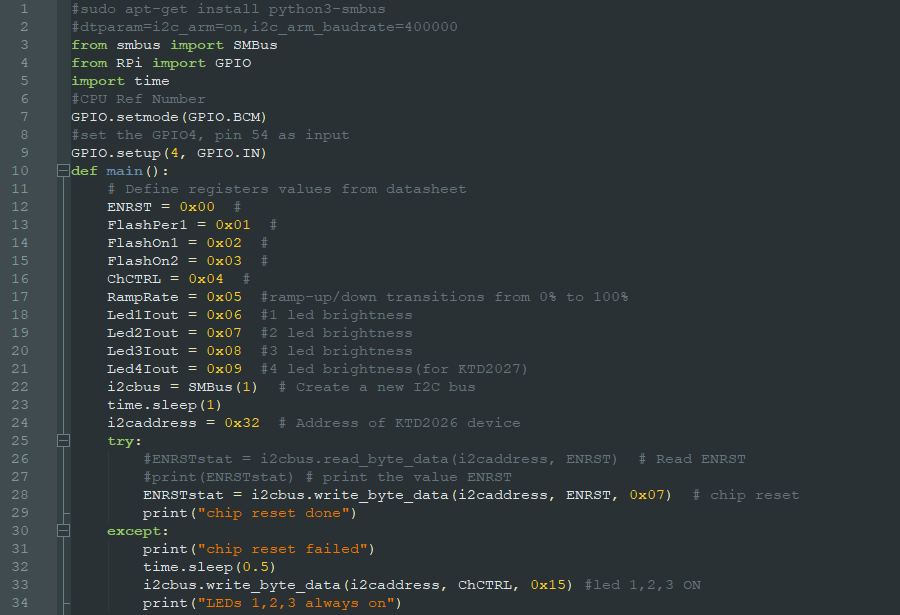
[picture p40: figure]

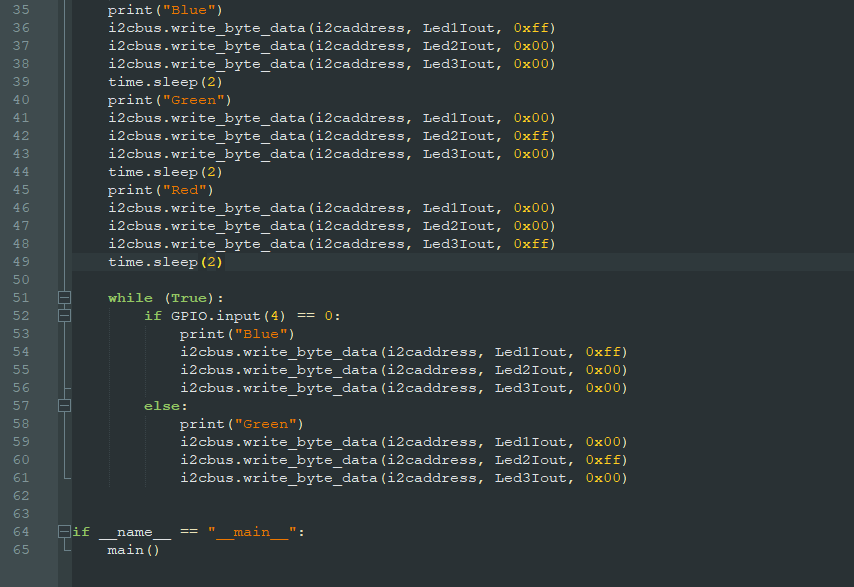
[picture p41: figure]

## Software Configuration

The öchìn board is only compatible with CM4 module with eMMC installed, because we

decided to not mount the SD card slot to save space. Having the eMMC instead of SD

also gives several advantages:

1. Faster than SD with speed up to 100Mbytes/s
2. More robust to physical corruption
3. Longer lifetime
4. More rugged

Having to write the ISO image directly to the eMMC is a bit more complicated than flash

an SD card, but not so much thanks to the great work done by Raspberry Pi.

The procedure to flash the CM4 module is well explained in the Raspberry Pi

Documentation:

https://www.raspberrypi.org/documentation/hardware/computemodule/cm-emmc-flashing.md

The procedure it’s straightforward, what you need to do in synthesis is the following:

1. Power up the board with boot configuration as “mass storage device”.
- To do so you need to power off the board (no Vin connected)
- Press the “nRPiboot” button on the external tiny board and, keeping it

pressed power up the board using the “Vin” Connector.

- Connect the board to your PC using the USB Type-C port
2. Run the “RPiboot” software, downloaded from the Raspberry Pi website. (https://github.com/raspberrypi/usbboot/raw/master/win32/rpiboot_setup.exe) After the

software starts, the PC will see the partition of the eMMC like if it would an SD

into the SDcard reader.

3. Flash the eMMC as you normally do with the SD. You could use Win32DiskImager

on Windows or “dd” command on Linux.

Once you have the system running for the first time, the USB interface will not work

because on CM4 it is disabled by default. To use the USBs, you need to enable them in

the “config.txt” file, adding the following line at the end of the file:

dtoverlay=dwc2,dr_mode=host

The “config.txt” file could be found within the “boot” partition. To be noted is that the

“boot” partition is also accessible when you connect the CM4 to the PC booted in MSD

mode, since it is formatted as FAT32.

NB

The Type-C VBUS is not connected to the power supply of the ochin board. This is to

not supply everything you may have attached to the HUB (Wi-Fi dongle, cameras etc..),

the power provided by the PC may not be sufficient. It means that if you only plug the

USB Type-C nothing is going to happens... To power on the board the supply on the

Vin connector is needed.

The Type-C VBUS it is used to switch the CM4 usb from the HUB to the Type-C port,

this is to be able to flash the eMMC. For this reason, during the normal operations, the

Type-C connector shouldn't be connected to anything.

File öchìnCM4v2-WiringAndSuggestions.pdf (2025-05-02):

## Introduction

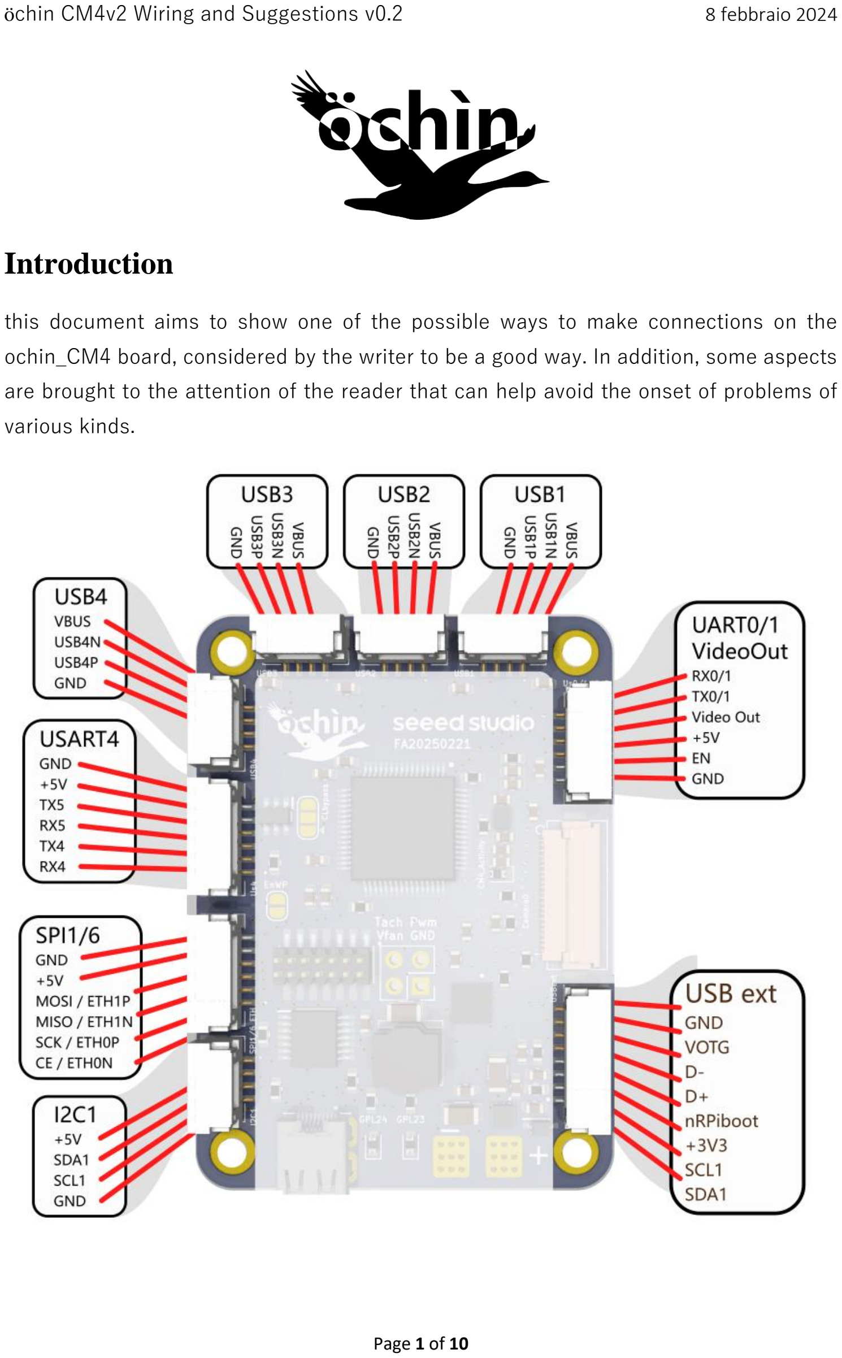
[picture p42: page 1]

öchin CM4v2 Wiring and Suggestions v0.2 | 8 febbraio 2024

this document aims to show one of the possible ways to make connections on the ochin_CM4 board, considered by the writer to be a good way. In addition, some aspects are brought to the attention of the reader that can help avoid the onset of problems of various kinds.

## Power Supply

The card accepts input voltages up to 28V, its internal regulator supplies 5V with currents up to 8Amps, therefore it is advisable to use cables with an adequate section. Choosing a cable with an adequate section avoids too high voltage drops. It is advisable to choose a cable with a section no longer less than AWG14.

The pads on which the power cables are soldered are copper squares perforated by a matrix of 9 metallized holes. The purpose of these vias is to increase the conductive surface by putting the 4 layers of the pcb in contact and also to provide more mechanical strength. In fact, once the wires have been soldered to the pcb, the tin that crosses the streets and reaches the bottom layer becomes a mechanical block through the pcb. This prevents the Top layer pads from tearing off the pcb following an accident. It is therefore advisable to verify that the pond has passed through the vias to the bottom layer.

## GHS cables

Except for the two cameras, the USB Type-C, microHDMI and the power pads, all other interfaces are accessible via 4 or 6 pin GHS connectors. Whether the cables with the connectors are purchased separately or supplied by Seeedstudio together with the ochin_CM4 board, it is important to NEVER TRUST THE COLOR CODE , because the color sequence of the cables can change from one manufacturer to another and is often random. So before connecting anything to the board it is important to check that the connections are correct regardless of the color of the cables.

Eventually it is possible and advisable to move the cables in the connector in order to have the colors consistent with their function.

The cable kit that comes with the ochin_CM4v2 board is as follows:

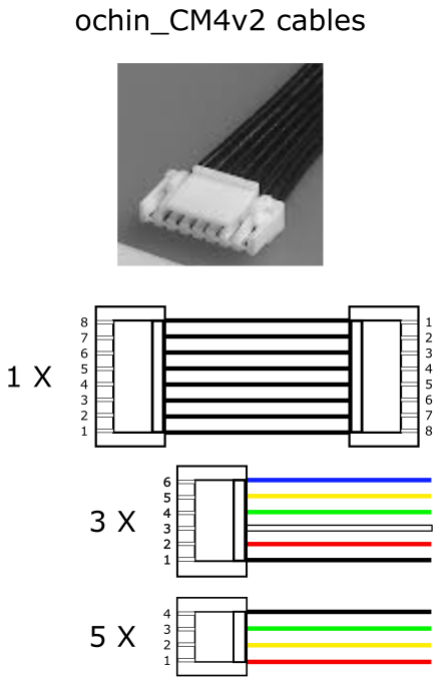
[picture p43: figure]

## USBs

The connections related to the USB ports are a bit critical, the reason for their criticality is the high frequency at which the USBs work. The maximum speed at which USB2 works is 480Mbps and a certain frequency is very important to ensure impedance coupling to avoid reflections and other deleterious phenomena. Understanding these phenomena requires in-depth studies and this document does not purport to explain any of this. This paragraph has the sole purpose of warning the reader that the connection of a USB device is not made by any 4 wires, as it can be for a serial or I2C device. The ochin_CM4 board uses SM04B-GHS connectors for USB with the aim of saving space, therefore it is not possible to use normal USB cables to connect devices to the board. However, it is advisable to connect a shielded USB cable to the GHS connector, cutting the wires as short as possible, because in the USB cable the cross-section of the wires, the material and thickness of the insulation and the way in which D + and D- are twisted make ensure that the cable has the right impedance. To do this, you can cut a USB cable and replace one of the connectors with the GHS.

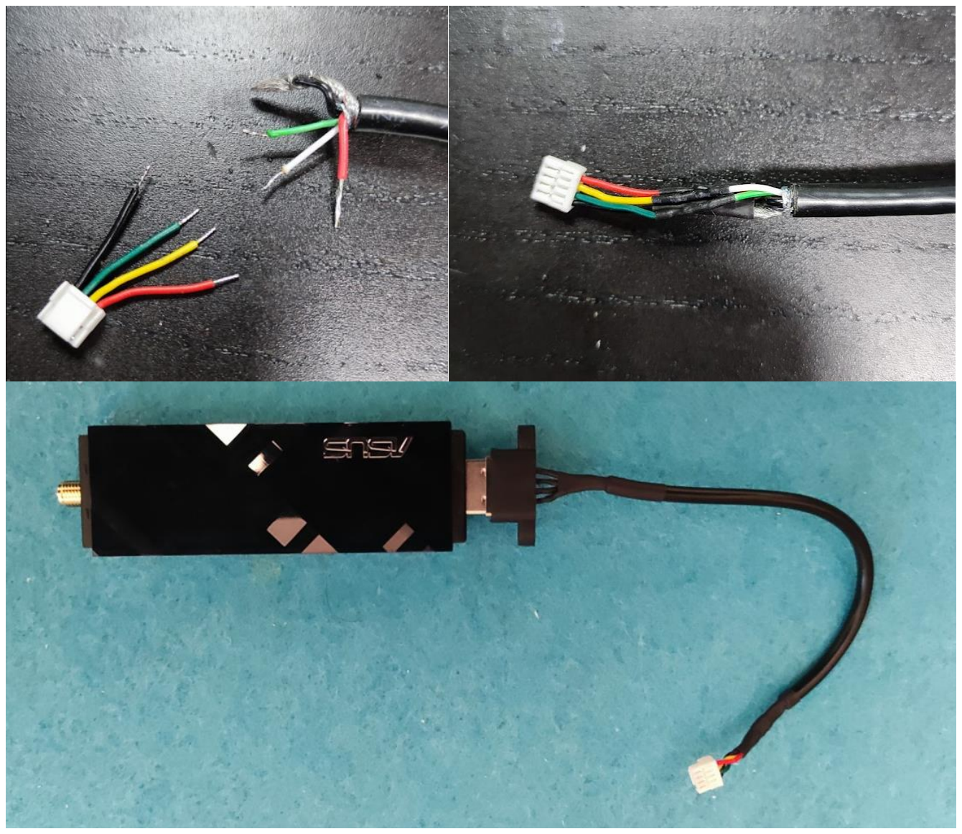
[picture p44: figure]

## SPI1/Ethernet

The connector, named SPI1/6, can be used to connect to either the SPI1/6 or the Ethernet port. In order to allow either connection, there are four smd (normally open) switches on the back of the ochin_CM4v2 board, which must be soldered appropriately.

In order to use the connector as SPI1/6, it is necessary to solder the jumpers between the central pad and the pad on the right (indicated by the word SPI1/6) of JP6,5,1,2 as shown in the following figure:


The order of the signals on the SPI1/6 connector is as follows


In the case of connecting to the Ethernet port of the RPI CM4, the smd switches JP6,5,1,2 should be soldered as follows:


In this case, the order of the signals on the SPI1/6 connector will be as follows:


An important note must be made regarding the Ethernet connection. In order to allow Ethernet connectivity and without affecting the size of the ochin_CM4v2 board, it was decided to adopt a transformerless configuration, like the one adopted and described by Texas Instruments in Application Note AN-1519 for their DP83848 Ethernet devices. It is therefore advisable to study and understand the AP-1519 before deciding to use the Ethernet port in a transformerless configuration.

The following image represents the connection diagram for connecting to the ochin_CM4v2 using a standard RJ45 cable:


## FCC/FPC camera connectors

There are several models of connectors compatible with flat cable manufacturers for Raspberry Pi Zero cameras (MIPI CSI 22 contacts 0.5mm pitch). After several tests of all compatible models, despite the not very small size, it was decided to use Hirose Electric FH12-22S-0.5SH (55). The main reasons are greater mechanical strength and easier positioning of the flat cable. However, it is important to be very careful to position the terminal part of the flat cable correctly and prevent the flat from being removed without having deactivated the mechanical block of the connector. If the flat is pulled out when blocked, it may happen that the pins of the connector scratch the copper surface of the contacts. In this case, seemingly random phenomena often occur in which the camera suddenly stops working or does not work at all. In these cases, it is advisable to check the status of the contacts with a magnifying glass.

It is also important to avoid subjecting the flat cable to too tight bends because they can cause the breakage of the support and the interruption of the connections printed on it.

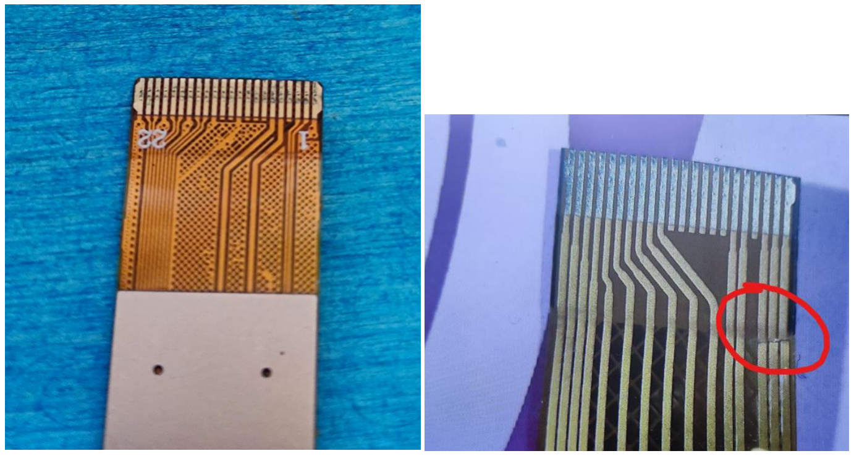
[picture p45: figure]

## Raspberry CM4 module mezzanine connectors

To mount the raspberry pi CM4 module, there are two 100 pins connectors on the back of the ochin_CM4 board. The two connectors are not vertically centered on the board, so it is quite easy to understand how the module is inserted. If the CM4 module is correctly inserted, the 4 mounting holes coincide with those of the ochin_CM4 board, otherwise the two remain misaligned. To mount the raspberry pi CM4 module, there are two 100 pins connectors on the back of the ochin_CM4 board. The two connectors are not vertically centered on the board, so it is quite easy to understand how the module should be plugged in. If the CM4 module is correctly inserted, the 4 mounting holes coincide with those of the ochin_CM4 board, otherwise the two remain misaligned.

The connectors are quite delicate and very dense, so you need to be careful. Before positioning the CM4 module, it is advisable to check that there are no specks of dust or other things that could prevent contact of the pins, if necessary clean with a brush and air. Place the module gently on the connectors until you feel they are seated in each other (there is a first zero force step where they snap into). When you are sure that the two boards are perfectly aligned and the connectors engaged, press the two long edges of the CM4 module until the connectors are fully inserted. It is advisable to limit the disassembly of the CM4 module as much as possible to avoid damaging the connector contacts.

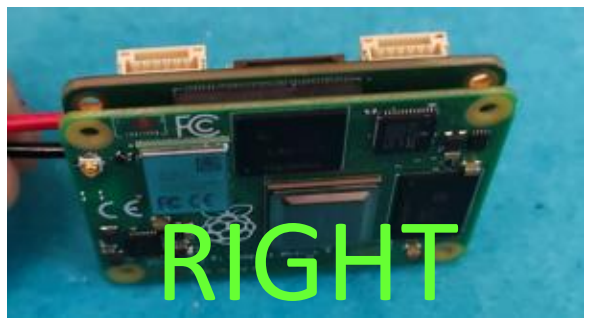
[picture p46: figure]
RIGHT

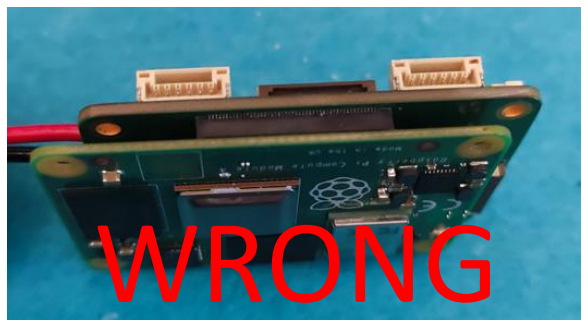
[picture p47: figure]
WRONG

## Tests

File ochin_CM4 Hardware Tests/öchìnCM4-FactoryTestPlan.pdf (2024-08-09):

Ochin CM4v2 carrier board Test Plan v0.1 | 30 ottobre 2023

## Introduction


The öchìn CM4 it’s a tiny carrier board for the Raspberry Pi Compute Module 4. It is designed for applications where a powerful machine with low consumption and small dimensions is required. The small form factor makes it interesting for all those applications where the space available is not much and containing the weight is important, such as in robotics, home automation and IOT.

The board is compatible with all Raspberry Pi CM4 modules equipped with eMMC. Depending on your needs, you can select a CM4 module with an SDRAM starting from 1GB up to 8GB and the eMMC from 8GB up to 32GB, with or without the WiFi / BT4 connection.

## Design

The board has the same dimensions as the RPi CM4 module, 55mm x 40mm with rounded corners. öchìn CM4 is composed of three parts, the carrier board itself and two covers, meant to protect the carrier board and the RPi CM4 module (to be purchased separately). The four cards thus form a stack of 18mm tall.
Several interfaces like USARTs, USBs are addressable bye the SM06B-GHS and SM04B-GHS connectors, available on the sides of the board. Two FCC/FPC connector are available to connect two MIPI CSI-2 cameras. The front cam is the “camera 1” which is a MIPI CSI-2 4lane camera. The side cam is the “camera 0” which is a MIPI CSI-2 2lane camera. The two FCC/FPC connectors have contacts on the bottom, the interface is the same used on the Raspberry Pi Zero.
On top of the board there is a 14x1.27mm connector, that could be used to connect a custom board on top, replacing the top PCB cover.
On the bottom of the öchìn carrier board there are the DF40HC(3.0)-100DS-0.4v mating connectors for the CM4 module. The bottom cover is meant to protect the boards and mount the whole stack. The bottom cover could be eventually replaced by a commercial heatsink for the CM4 module.

## Hardware interfaces

The öchìn CM4 board provides the following interfaces on the side’s connectors:

- 4x USB 2.0 480Mbps (4x SM04B-GHS-TB(LF)(SN) connectors)
- 1x USB Type-C (for flashing eMMC)
- 2x CSI camera (2x FH12-22S-0.5SH (55) connectors)
- I2C1 (SM04B-GHS-TB(LF)(SN) connector)
- SPI1 / 6 (SM06B-GHS-TB(LF)(SN) connector)
- UART0 / 1 + Video Out (SM06B-GHS-TB(LF)(SN) connector)
- UART4 / UART5 (SM06B-GHS-TB(LF)(SN) connector)
- 1x microHDMI
- 2x general purpose LEDs
- 1x RGB LED on external tiny board
- 1x general purpose button on external tiny board

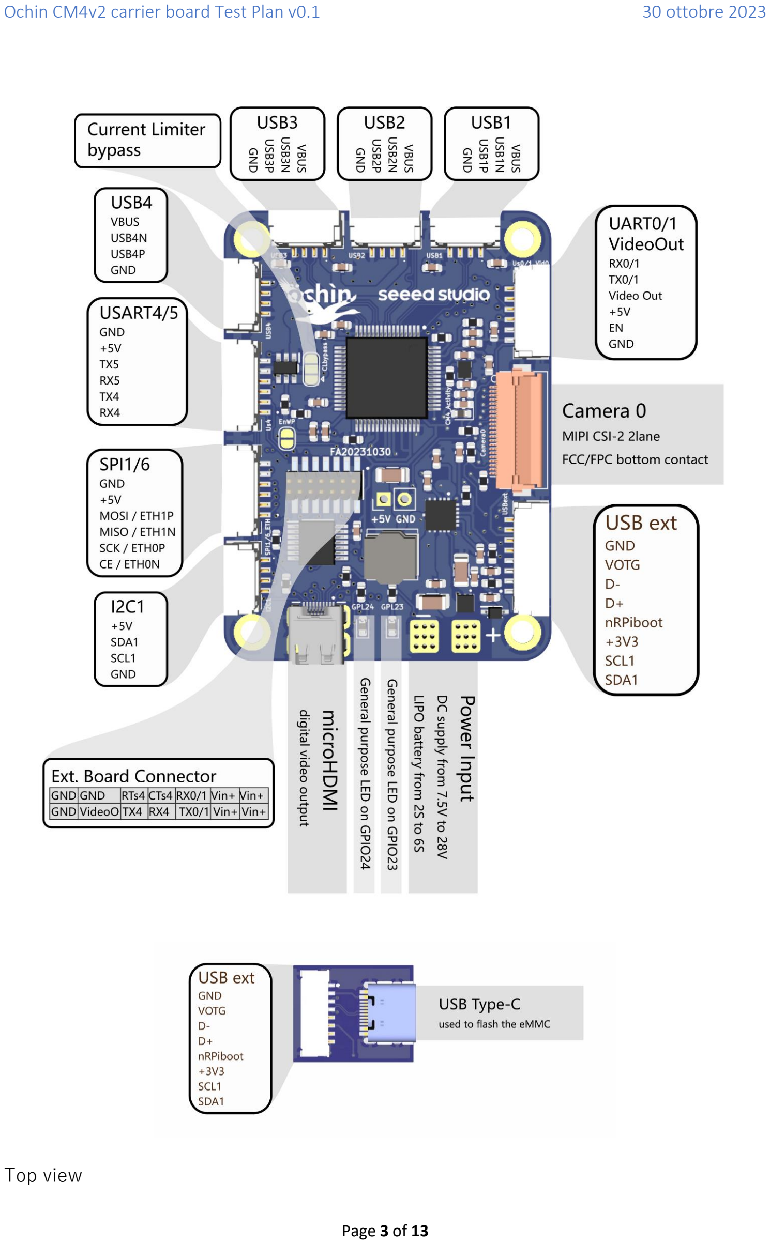
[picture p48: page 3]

Top view

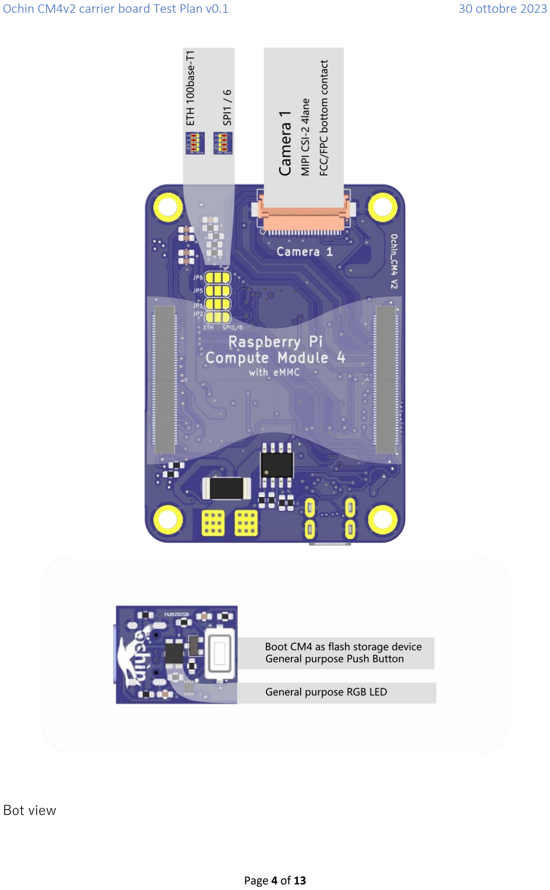
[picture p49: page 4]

Bot view

## Tools for tests

1. ochin CM4 carrier board
2. Raspberry Pi CM4 module with eMMC
3. Power Supply 0-30Vdc
4. USB cable Type-C
5. JST GHR-04V-S with cables
6. JST GHR-06V-S with cables
7. USART to USB adapter
8. USB Type-A female adapter
9. RaspiCam for Raspberry Pi Zero (FPC-22 pin flat cable)
10. USB memory stick

To test the functionality of the USBs and other interfaces you need some JST GH series

connectors:

- USB1-4 : JST GHR-04V-S
- I2C1 : JST GHR-04V-S
- UART0/1 Video Out : JST GHR-06V-S
- UART4/5 : JST GHR-06V-S
- SPI1/6 : JST GHR-06V-S
- USBxFlash: JST GHR-08-S <-> JST GHR-08-S

## Test Plan

The test plan is thought to verify the design and the fabrication of the board.

The first step is to verify the power supply circuit:

1. Test with forward voltage and +5Vdc regulator
2. Test of the inverted voltage protection

Once the supply circuit is tested, we must flash the eMMC of the CM4 module and verify

that the other peripherals are working fine.

1. Test the UART0, used by default as debug terminal.
2. Redirect terminal on UART4, UART5 and test the interfaces

3. Verify that the USBs works fine.
4. Verify that the MIPI Camera0 and Camera1 works fine.
1) Power Supply circuits. Forward Voltage circuit Test:
1. In this phase the CM4 module SHOULD NOT BE MOUNTED on the ochin carrier

board

2. Apply a voltage between 7,5Vdc and 25Vdc on the power pad. The positive pole

is the one on the right and negative pole is on the left (top view).

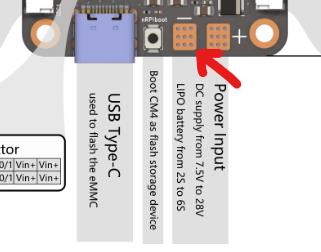
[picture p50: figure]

3. Verify the voltage on the source pin of the SIA471DJ mosfet, placing the

multimeter across the C11 capacitor. The voltage passes through the mosfet and

we should find on C11 the same voltage of Vin.

4. If the voltage on C11 is fine, it is possible to verify the +5V on the output of the

switching regulator. To check the +5V we can measure the voltage across +5V

connector over the inductor L1. The measured voltage should be +5Vdc.

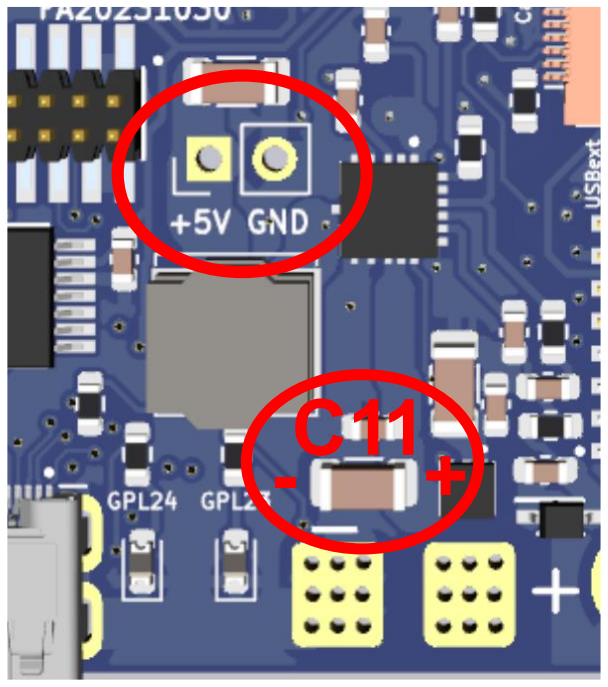
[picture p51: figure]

2) Power Supply circuits. Inversion polarity protection circuit Test:

The ochin board is equipped with a reverse protection circuit. The power supply is

blocked in case of inversion thanks to the U1-SIA471DJ mosfet. In the case that the Vin

is mistakenly reversed, the gate of the mosfet-p opens the junction, preventing current

to pass and damage the board.

To verify its operation, it is sufficient to arbitrarily invert the polarity of Vin and therefore

check that the voltage across C11 is equal to zero.

### 1. To prevent the CM4 module from being damaged in the event of a protection

malfunction, it is advisable to perform the test with the CM4 module NOT

mounted.

2. Apply a reverse voltage between 7,5Vdc and 25Vdc on the power pad. The positive

pole is the one on the left and negative pole is on the right (top view).

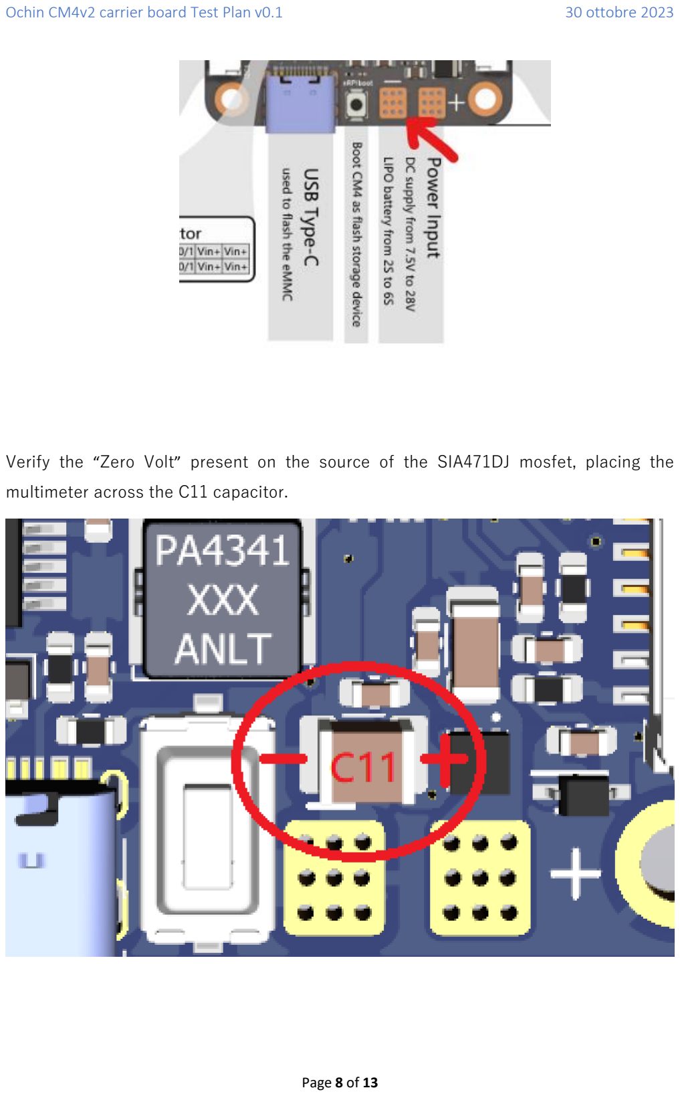
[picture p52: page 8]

Verify the “Zero Volt” present on the source of the SIA471DJ mosfet, placing the

multimeter across the C11 capacitor.

## Power up the CM4 Module

The procedure to flash the CM4 module is well explained in the Raspberry Pi

Documentation:

https://www.raspberrypi.org/documentation/hardware/computemodule/cm-emmc-flashing.md

The procedure it’s straightforward, what you need to do in synthesis is the following:

1. Power up the board with boot configuration as “mass storage device”.
- To do so you need to power off the board (no Vin connected)
- Connect the board to your PC using the USB Type-C port
- Press the “nRPiboot” button and, keeping it pressed power up the board

providing Vin (the USBC does not power up the board).

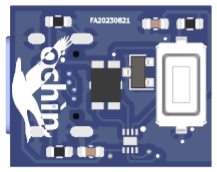
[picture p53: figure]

2. Run the “RPiboot” software, downloaded from the Raspberry Pi website (github).

After the software starts, the PC will see the partition of the eMMC like if it would

an SD into the SD-card reader.

3. Flash the eMMC as you normally do when you want to flash an image to the SD

card. You could use Win32DiskImager on Windows or “dd” command on Linux.

## UARTs test

To have the terminal output on the UART0 port, we must disable the BT4 module and

enable the UART0 in the “config.txt” file, adding the following line at the end of the file:

dtoverlay=disable-bt

BOOT_UART=1

The “config.txt” file could be found within the “boot” partition. To be noted is that the

“boot” partition is also accessible when you connect the CM4 to the PC booted in MSD

mode, since it is formatted as FAT32.

To connect the UART0 to the pc and connect the debug terminal, we must use an USB-

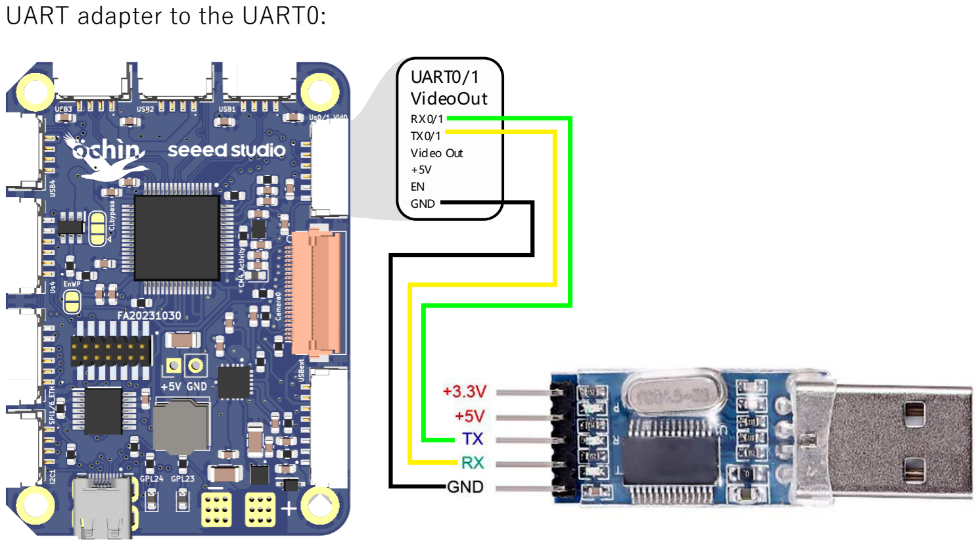
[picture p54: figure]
UART adapter to the UART0:

To interface to the CM4, a serial terminal software like Putty or Teraterm is needed.

To test the other UART interfaces we need to enable it from the “config.txt” file:

dtoverlay=uart3, # without flow control pins

dtoverlay=uart4,ctsrts # with flow control pins

dtoverlay=uart5,

And connect them to other UART2USB adapters.

To test the functionality of all the UARTs, it is possible to redirect one UART to another.

$ tty #identify the actual UARTs

$ exec &> >(tee >(cat >&/dev/ttyAMAx) #redirect to ttyAMAx

## USBs test

Once you have the system running for the first time, the USB interface will not work

because it is disabled by default. To use the USBs, you need to enable it in the

“config.txt” file, adding the following line at the end of the file:

dtoverlay=dwc2,dr_mode=host

To enable the USBs1-4, the USB Type-C cable must be disconnected from the

board!! Otherwise, the USB hub is powered off.

To test the USBs functionality is possible to make a speed test to an external USB

Memory Storage device, for example an USB Stick.

To connect the USB stick to the ochin board in necessary to make an adapter cable

using a USB Type-A female connector and a JST GHR-04V-S with cables:

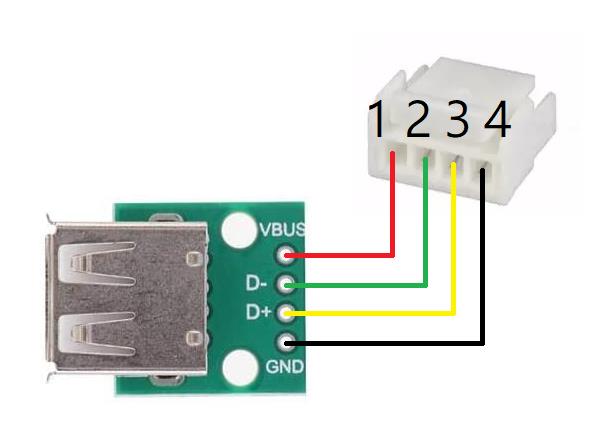
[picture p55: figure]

To test the write and read speed to the external device use the following command from

the Linux prompt of the raspberry pi cm4.

Go to the external drive location under /media/pi/
First test the write speed:

$ dd if=/dev/zero of=/media/usb/output.file bs=20M count=5 oflag=direct

at the end you will receive the write speed to the external disk:

104857600 bytes (105 MB, 100 MiB) copied, 0.815855 s, 129 MB/s s

Run the following command to clear the memory cache:

$ sudo sh -c "sync && echo 3 > /proc/sys/vm/drop_caches"

Then measure the read speed:

$ dd if=/media/usb/output.file of=/dev/zero bs=20M count=5 oflag=dsync

104857600 bytes (105 MB, 100 MiB) copied, 0.5172 s, 203 MB/s

## CSI-2 MIPI Cameras test

To test the CSI camera, a streaming sw is necessary. One of my favorites is MJPG-

streamer, use the following commands to install it:

sudo apt-get update

sudo apt-get upgrade

sudo apt-get install cmake libjpeg8-dev

git clone https://github.com/jacksonliam/mjpg-streamer

tar xvzf mjpg-streamer.tar.gz

sudo apt-get install libjpeg8-dev

sudo apt-get install imagemagick

cd mjpg-streamer/mjpg-streamer

comment out the two #include inside of “mjpg-streamer/utils.c”

//#include <linux/stat.h>

//#include <sys/stat.h>

make

To start streaming from the “Camera1” use the following line:

$ ./mjpg_streamer -o "output_http.so -w ./www" -i "input_raspicam.so"

To view the stream, open the following URL from a pc within the same LAN/WLAN

http://raspberrypi.local:8080/stream.html

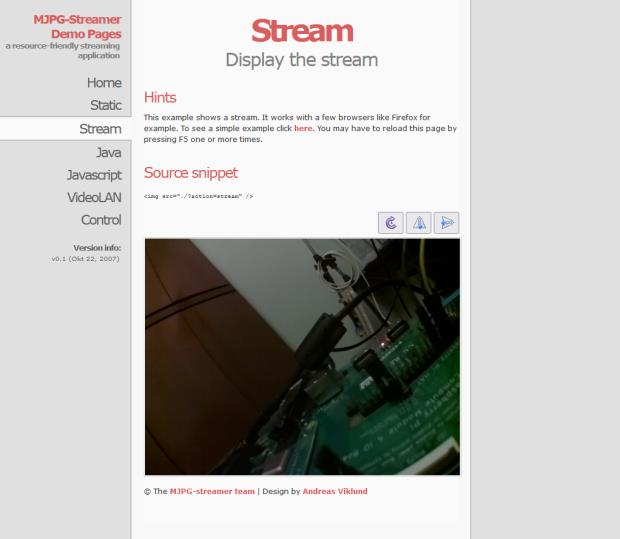
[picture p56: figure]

## GPL1 and GPL2 leds test

To test the two general purpose LEDs you can use the python script called LEDs_test.py.

The program will turn on the two LEDs alternately to test their operation.

## RGB led test

To test the operation of the RGB LED mounted on the external board, you can run the

python script called KTD2026_test.py. The program will run a loop in which the basic

colors (RGB) and some secondary colors will be produced.

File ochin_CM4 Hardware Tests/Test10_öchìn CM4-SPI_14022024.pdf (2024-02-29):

Ochin CM4v2 carrier hardware tests v0.1 | 14 febbraio 2024


## ochin_CM4v2 Hardware test number 10

## SPI test

Devices used for tests

1. ochin CM4v2 carrier board
2. Raspberry Pi CM4 module with eMMC
3. Power Supply 0-30Vdc
4. An SPI device

Test description

The purpose of this test is to verify the proper functioning of the SPI interface of the CM4 module.

Preliminary configuration

The connector, named SPI1/6, can be used to connect to either the SPI1/6 or the Ethernet port. In order to allow either connection, there are four smd switches (normally open) on the back of the ochin_CM4v2 board, which must be soldered appropriately.

In order to use the connector as SPI1/6, it is necessary to solder the jumpers between the central pad and the pad on the right (indicated by the word SPI1/6) of JP6,5,1,2 as shown in the following figure:


The order of the signals on the SPI1/6 connector is as follows


To test the functionality of the SPI, it is necessary to enable it by using the “raspi-

config” software or entering the following line within the file "boot/config.txt"

dtparam=spi=on

Test execution

To test the functionality of the SPI interface, it is necessary to connect the ochin an

SPI device (any device) and establish communication.

Test result

Test passed

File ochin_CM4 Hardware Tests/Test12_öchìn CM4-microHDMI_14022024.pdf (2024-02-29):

Ochin CM4v2 carrier hardware tests v0.1 | 14 febbraio 2024


## ochin_CM4v2 Hardware test number 12

## microHDMI test

Devices used for tests

1. ochin CM4v2 carrier board
2. Raspberry Pi CM4 module with eMMC
3. Power Supply 0-30Vdc
4. microHDMI<->HDMI cable
5. HDMI monitor

Test description

the purpose of this test is to verify the proper functioning of the microHDMI, available on the ochin board. A software called FBI will be used to test the HDMI video interface.

Preliminary configuration

The purpose of the test is to display a test image on the monitor. Since the graphical

GUI is not available, it is necessary to install the FBI sw, which can display an image

from the terminal.

Installation of FBI:

Sudo apt-get update

sudo apt-get -y install fbi

It is also necessary to copy the test image "monoscope-1280x720.jpg" to an accessible folder.

To do this, it is advisable to use an FTP client.

Ochin CM4v2 carrier hardware tests v0.1 | 14 febbraio 2024

Test execution

To view the monoscope you need to move to the folder where you copied the file

"monoscope-1280x720.jpg" and run the following command:

fbi -a monoscope-1280x720.jpg

After sending the command, the monoscope image should appear on the monitor.

Test result

Test passed

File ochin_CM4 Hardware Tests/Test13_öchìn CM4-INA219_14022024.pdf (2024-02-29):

Ochin CM4v2 carrier hardware tests v0.1 | 14 febbraio 2024


## ochin_CM4v2 Hardware test number 13

## INA219 test

Devices used for tests

1. ochin CM4v2 carrier board
2. Raspberry Pi CM4 module with eMMC
3. Power Supply 0-30Vdc

Test description

The purpose of this test is to verify the proper functioning of the INA219 power monitor, available on the ochin board.

Preliminary configuration

In order to test the INA219 chip, it is necessary to enable the I2C1 interface.
The I2C interface could be enabled via raspi-config or directly adding the following lines in the boot/config.txt file:
dtparam=i2c_arm=on,i2c_arm_baudrate=400000

To interface the chip it’s also needed to install the python libraries: sudo apt-get install python3-smbus sudo pip3 install pi-ina219

Test execution

To test the operation of INA219, simply run the python script "ina219_test.py”:

python ina219_test.py

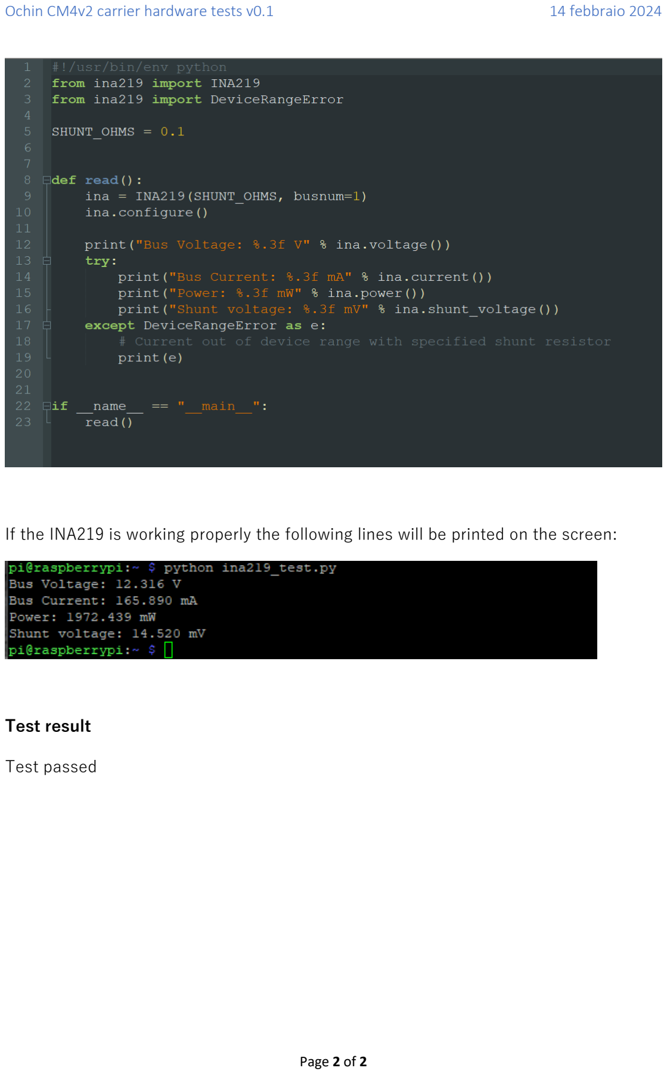
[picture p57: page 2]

Ochin CM4v2 carrier hardware tests v0.1 | 14 febbraio 2024

If the INA219 is working properly the following lines will be printed on the screen:

Test result

Test passed

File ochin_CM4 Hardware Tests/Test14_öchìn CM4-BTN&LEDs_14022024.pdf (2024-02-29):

Ochin CM4v2 carrier hardware tests v0.1 | 14 febbraio 2024


## ochin_CM4v2 Hardware test number 14

## Button and LEDs test

Devices used for tests

1. ochin CM4v2 carrier board
2. Raspberry Pi CM4 module with eMMC
3. Power Supply 0-30Vdc

Test description

The purpose of this test is to verify the proper functioning of the S1 button located on the external board and the two leds available on the main ochin board.

Button S1 is connected to GPIO4 normally high input, when S1 is pressed GPIO4 goes

to logic low level. The anodes of the two LEDs are connected to GPIO23 and GPIO24

outputs, so they will light up when the two outputs are at logic high level.

If the LEDs and the button are working well, you will have GPIO23 LED off and GPIO24 LED on. When button S1 is pressed, the GPL23 led will turn on and the GPL24 led will turn off.

Ochin CM4v2 carrier hardware tests v0.1 | 14 febbraio 2024

Test execution

In order to test the S1 button and the two LEDs GPL23 and GPL24, simply run the

python script "BTNnLEDs_test.py."

python BTNnLEDs _test.py

Test result

Test passed


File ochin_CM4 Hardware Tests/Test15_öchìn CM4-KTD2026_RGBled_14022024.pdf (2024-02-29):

Ochin CM4v2 carrier hardware tests v0.1 | 14 febbraio 2024


## ochin_CM4v2 Hardware test number 15

## KTD2025 RGB LED test

Devices used for tests

1. ochin CM4v2 carrier board
2. Raspberry Pi CM4 module with eMMC
3. Power Supply 0-30Vdc

Test description

The purpose of this test is to verify the proper functioning of the RGB LED located on the external board ochin board.

Management of the RGB LED is entrusted to a chip called KTD2026, which is

connected to the CM4 module via the I2C1 interface.

Using the I2C libraries, it is possible to configure the chip to vary the intensity of each

of the three basic colours and their respective transitions. For more precise and

detailed information on the handling of the chip, it is necessary to study the datasheet

of the KTD2026, available on the website of the manufacturer, Kinetic Technologies

(https://www.kinet-ic.com).

Preliminary configuration

In order to test the INA219 chip, it is necessary to enable the I2C1 interface.
The I2C interface could be enabled via raspi-config or directly adding the following lines in the boot/config.txt file:
dtparam=i2c_arm=on,i2c_arm_baudrate=400000

To access the I2C interface via Python, the libraries must first be installed:

sudo apt-get install python3-smbus

Test execution

In order to test the S1 button and the KTD2026, simply run the python script "

KTD2026_test" :

python KTD2026_test



If the driver is working properly, at first the LED will be colored the three basic colors

(Blue, Green, Red) and then all combinations will be displayed in an infinite cycle.

Test result

Test passed

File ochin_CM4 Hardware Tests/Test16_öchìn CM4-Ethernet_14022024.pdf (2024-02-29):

Ochin CM4v2 carrier hardware tests v0.1 | 14 febbraio 2024


## ochin_CM4v2 Hardware test number 16

## Ethernet test

Devices used for tests

1. ochin CM4v2 carrier board
2. Raspberry Pi CM4 module with eMMC
3. Power Supply 0-30Vdc
4. RJ45-GHS adapter
5. Ethernet switch

Test description

The purpose of this test is to verify the proper functioning of the Ethernet interface of the CM4 module.

Preliminary configuration

The connector, named SPI1/6, can be used to connect to either the SPI1/6 or the Ethernet port. In order to allow either connection, there are four smd switches (normally open) on the back of the ochin_CM4v2 board, which must be soldered appropriately.

In order to use the connector as SPI1/6, it is necessary to solder the jumpers between the central pad and the pad on the right (indicated by the word SPI1/6) of JP6,5,1,2 as shown in the following figure:


The order of the signals on the SPI1/6 connector is as follows


In the case of connecting to the Ethernet port of the RPI CM4, the smd switches JP6,5,1,2 should be soldered as follows:


In this case, the order of the signals on the SPI1/6 connector will be as follows:


An important note must be made regarding the Ethernet connection. In order to allow Ethernet connectivity and without affecting the size of the ochin_CM4v2 board, it was decided to adopt a transformerless configuration, like the one adopted and described by Texas Instruments in Application Note AN-1519 for their DP83848 Ethernet devices. It is therefore advisable to study and understand the AP-1519 before deciding to use the Ethernet port in a transformerless configuration.

The following image represents the connection diagram for connecting to the ochin_CM4v2 using a standard RJ45 cable:


Test execution

To test the functionality of the Ethernet interface, it is necessary to connect the ochin

to an Ethernet switch by means of the adapter and an RJ45 cable. If the test is

successful, you will be able to access the 100baseT Ethernet network.

Test result

Test passed

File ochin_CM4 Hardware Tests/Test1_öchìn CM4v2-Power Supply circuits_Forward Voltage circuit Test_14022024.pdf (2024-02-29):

Ochin CM4v2 carrier hardware tests v0.1 | 14 febbraio 2024


## ochin_CM4v2 Hardware test number 1

## Power Supply circuits:

## Forward Voltage circuit

Devices used for tests

1. ochin CM4 carrier board
2. Raspberry Pi CM4 module with eMMC
3. Multimeter
4. Power Supply 0-30Vdc

Test description

This test is intended to verify the operation of the power supply circuit for the CM4

module. First you need to check that the reverse voltage protection mosfet lets the

input voltage pass. Secondly, it is necessary to measure that 5Vdc is present on the

output of the switching regulator for the power supply of the Raspberry Pi CM4

module.

Test execution

1. In this phase the CM4 module SHOULD NOT BE MOUNTED on the ochin carrier

board since it is not needed for the test.

2. Apply a voltage between 7,5Vdc and 25Vdc on the power pads. The positive pole

is the one on the right and the negative pole is on the left (top view).


3. Verify the voltage on the source pin of the SIA471DJ mosfet, placing the

multimeter across the C11 capacitor. The voltage pass through the mosfet and

we should find on C11 the same voltage of Vin.

4. If the voltage on C11 is fine, it is possible to verify the +5V on the output of the

switching regulator. To check the +5Vdc we can measure the voltage on the pads

close to the inductor.

Test results


The test was performed numerous times on different boards and never presented any

problems.

Test Passed

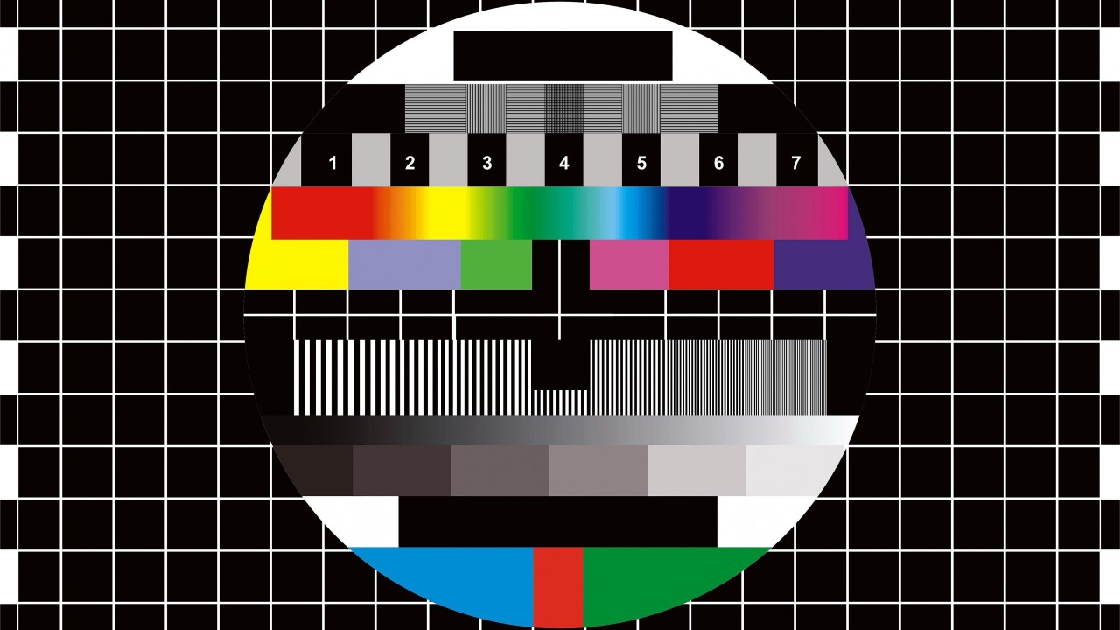
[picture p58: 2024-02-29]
ochin_CM4 Hardware Tests/files/monoscope-1280x720.jpg

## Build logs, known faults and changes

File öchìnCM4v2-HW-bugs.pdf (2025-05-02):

öchin CM4 HW bugs v0.2 | 2 maggio 2025

## Introduction


This document provides a comprehensive list of hardware issues identified on the öchìn CM4v2 board during its development and testing phases. Each issue is detailed with a description, its impact, and the specific hardware version where it was resolved.

The goal of this document is to assist developers, engineers, and users in understanding potential limitations of the board and ensuring compatibility with their projects. For any additional questions or updates, please refer to the official documentation or contact support.

## Bugs list

Title: INA219 burns out on reverse polarity BugID: HW-001 Date: November 2024 Description: If the polarity of the öchìn CM4v2 board is inadvertently reversed, the protection circuit will safeguard both the öchìn board and the CM4 module. However, the current sensor INA219 will suffer irreversible damage. This results in a malfunction
of | the | current | and | voltage | readings | for | the | power | supply.
Impact: The board's ability to measure current and voltage is compromised, requiring
replacement | of | the INA219 chip | to | restore | functionality.
Resolution: This issue has been resolved in version öchìn CM4v2.0.1 by improving the protection circuit.

Title: Radxa CM5 emmc Flash BugID: HW-002 Date: November 2024
Description: This is not a real bug, but it prevents the Ochin board from putting the Radxa CM5 module into DFU mode to flash the internal memory.
Impact: As a result, even when the boot button is pressed, the module attempts to boot normally instead of entering USB boot mode.
Resolution: This issue has been resolved in version öchìn CM4v2.0.1

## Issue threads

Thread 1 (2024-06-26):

KiCad files

richard-scott, 2024-06-26:
Please add the KiCad files to your repo so you can meet the requirements for the GPLv3.

pernicious-flier, 2024-07-19:
Hi richard-scott, the license is for the documentation related to the ochin_CM4v2 board and not the board itself, the license is therefore respected. I am sorry but as I have explained in the past, it is precisely to defend the project that I decided not to provide the sources. For those who want to make a similar board or understand how it was made, he will find all the necessary information (including schematics) in the documentation.
Gerbers would be useless to any maker, as it is not possible to assemble such a board by hand guaranteeing its operation.
Not to mention the costs that would be much higher than the price at which it is sold by Seeedstudio.
These are the reasons, I think they are understandable and also in the interest of those who want this project to continue to exist.
Thank you for the question, I will add a note in the README.md of the project as soon as possible so as to clarify what the license is about.
Best, Flavio

pernicious-flier, 2024-07-19:
Ok , thank you for bringing it to my attention, I will read it as soon asap and consider whether I should use a more suitable license.

Closed 2024-07-19.

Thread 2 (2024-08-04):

Wrong pinout on manual for USB EXT

Davidsastresas, 2024-08-04:
Hi, we just purchased a few of these boards from seedstudio, and we were setting them up when we realized the USB EXT might be wrongly represented in the manual here:

https://github.com/ochin-space/ochin-CM4v2/blob/master/%C3%B6ch%C3%ACn%20CM4v2%20-%20Manual.pdf

We are pretty sure the pins are really the other way around as to how they are represented in the picture. So:

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

Would be instead, top to bottom, checking the pins as they are on that picture, with connectors on top and HDMI pointing down:

GND
VOTG
D+
D-
nRPiboot
+3V3
SCL1
SDA1

Is this correct? Can anybody confirm? Thanks!

pernicious-flier, 2024-08-09:
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

Hello David, thanks for the message i will check asap and let you know!
Best Flavio

pernicious-flier, 2024-08-09:
Hello Davidsastresas, you were right... i've updated manual and pics.

Thanks a lot, Flavio

Closed 2024-08-09.

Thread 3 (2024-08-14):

Ethernet setup not working

Davidsastresas, 2024-08-14:
Hi,

We purchased some of these boards from seedstudio. We verified several peripherals now, but we are having trouble with Ethernet port.

We soldered the jumpers as indicated in the manuals, and it seems the interface, drivers etc are on place, only it does not detect a valid connetion.

We also think it is correctly wired, and wires should be short enough ( similar wiring has been tested succesfully on other transformeless setups ), see photo attached:
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

Before spending more time debugging it I wanted to check here first if anybody got this working already, or if I am missing something additional. Thanks!

pernicious-flier, 2024-08-19:
Hello David,
i confirm that the wiring seems to be fine, let me check on the latest board i received and i will let you know.
Best Flavio

Davidsastresas, 2024-08-19:
Thank you very much Flavio.

Happy to read you confirm wiring to be fine. My first thought was wiring, so I got paranoid and checked continuity all the way up to cm4 pins.

I flashed a normal RPI OS image, and after not managing to make it work I also placed the custom ochin dt-blob.bin, although I don't think ethernet is managed there at all.

I also did a quick debug checking drivers and interfaces were up and running on my cm4, and it seems they were, everything pointed to a hardware or wiring issue.

I have 2 of these boards around, I will test the second one next time in case it is a faulty board.

Let me know if you find any anditional info that could help me. Thank you very much!

pernicious-flier, 2024-08-19:
Hello David,
i've tested the board connected through a TPlink AP and also p2p to an
ethernet camera and worked just fine. Let me test it again on the
seeedstudio latest board. I will let you know asap (hope in a couple of
days).
Best Flavio

Il giorno lun 19 ago 2024 alle ore 13:41 David Sastre <
***@***.***> ha scritto:

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

pernicious-flier, 2024-08-20:
Hello David,
I have a question about your wirings, just to be sure: do the two devices
(ochin and the other ethernet device) share a common ground?
When one or both devices are transformerless the ground should be in common
to avoid the ground loop caused by the difference of potential of the two
grounds.
I don't see the ground connection in your photo, but the ground is the "-"
of the supply, if you power the two devices from the same source the ground
is already in common.
Please let me know,
Best, Flavio

Il giorno lun 19 ago 2024 alle ore 13:41 David Sastre <
***@***.***> ha scritto:

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

Davidsastresas, 2024-08-26:
Thank you very much Flavio.

When I read your answer I got very happy because indeed I was powering the devices on 2 different power supplies and they didn't share ground, thanks for providing that info, I didn't realize!

However, I connected a common ground between the 2 of them ( gnd on ethernet port in ochin and ground directly on power supply of the other device ) and still not success.

Very frustrating, I am sure it is some dumb detail, but I am not managing to find the key. Please let me know if you think of anything else. I will report back if any news. Thank you!

Davidsastresas, 2024-08-27:
I just got it working. I set up a second ochinv2 board, compute module, wiring, jumpers, etc from scratch and it is working now, even without common ground.

so most likely something was faulty on the first setup. Sorry for the trouble, and thank you very much for answering back. I am closing this one.

pernicious-flier, 2024-08-27:
Thanks David to let us know, i appreciate it👍
Have fun with the ochins!

> I just got it working. I set up a second ochinv2 board, compute module, wiring, jumpers, etc from scratch and it is working now, even without common ground.
>
> so most likely something was wrong on the first setup. Sorry for the trouble, and thank you very much for answering back. I am closing this one.

Closed 2024-08-27.

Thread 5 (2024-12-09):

CM5

rapolasm, 2024-12-09:
Hello,

Has anyone tested this board with the new CM5? Is there any indications it would work?
From the early information available online I assume that most of the pins are the same (https://atctwo.net/projects/pinout/?device=cm5)

pernicious-flier, 2025-01-13:
Hello rapolasm, there are some differences (for example the pin used for cam0 on cm4 are used for usb3 on cm5 and not sure abt i2c1). It could work but not 100% sure (not tested yet).

Closed 2025-01-13.

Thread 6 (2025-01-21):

Ochin for cm5

smatton, 2025-01-21:
Hello,

Any plans to develop a similar board for cm5 with 4 lane csi and pcie connector?

pernicious-flier, 2025-02-26:
Hello smatton,
yes.. i'm thinking abt it. There are some pros and cons with the cm5, but it's the future i suppose, so..

pernicious-flier, 2025-02-26:
Hello smatton,
yes.. i'm thinking abt it. There are some pros and cons with the cm5, but it's the future i suppose, so..

smatton, 2025-02-26:
The current board does work with the cm5, but it would be great to add the pcie capability so that the hailo AI accelerators could be utilized. I think the cm4 also has pcie lanes as well and could utilize the hailo accelerators as well?

pernicious-flier, 2025-02-26:
> The current board does work with the cm5, but it would be great to add the pcie capability so that the hailo AI accelerators could be utilized. I think the cm4 also has pcie lanes as well and could utilize the hailo accelerators as well?

Yes, the CM4 also have the PCIe interface but the ochin board doesn't... the reason is not enough room for connectors. Since the CM5 doesn't have the second CSI camera, i'll have some space for something else, it could be an USB3 or the PCIe let's see

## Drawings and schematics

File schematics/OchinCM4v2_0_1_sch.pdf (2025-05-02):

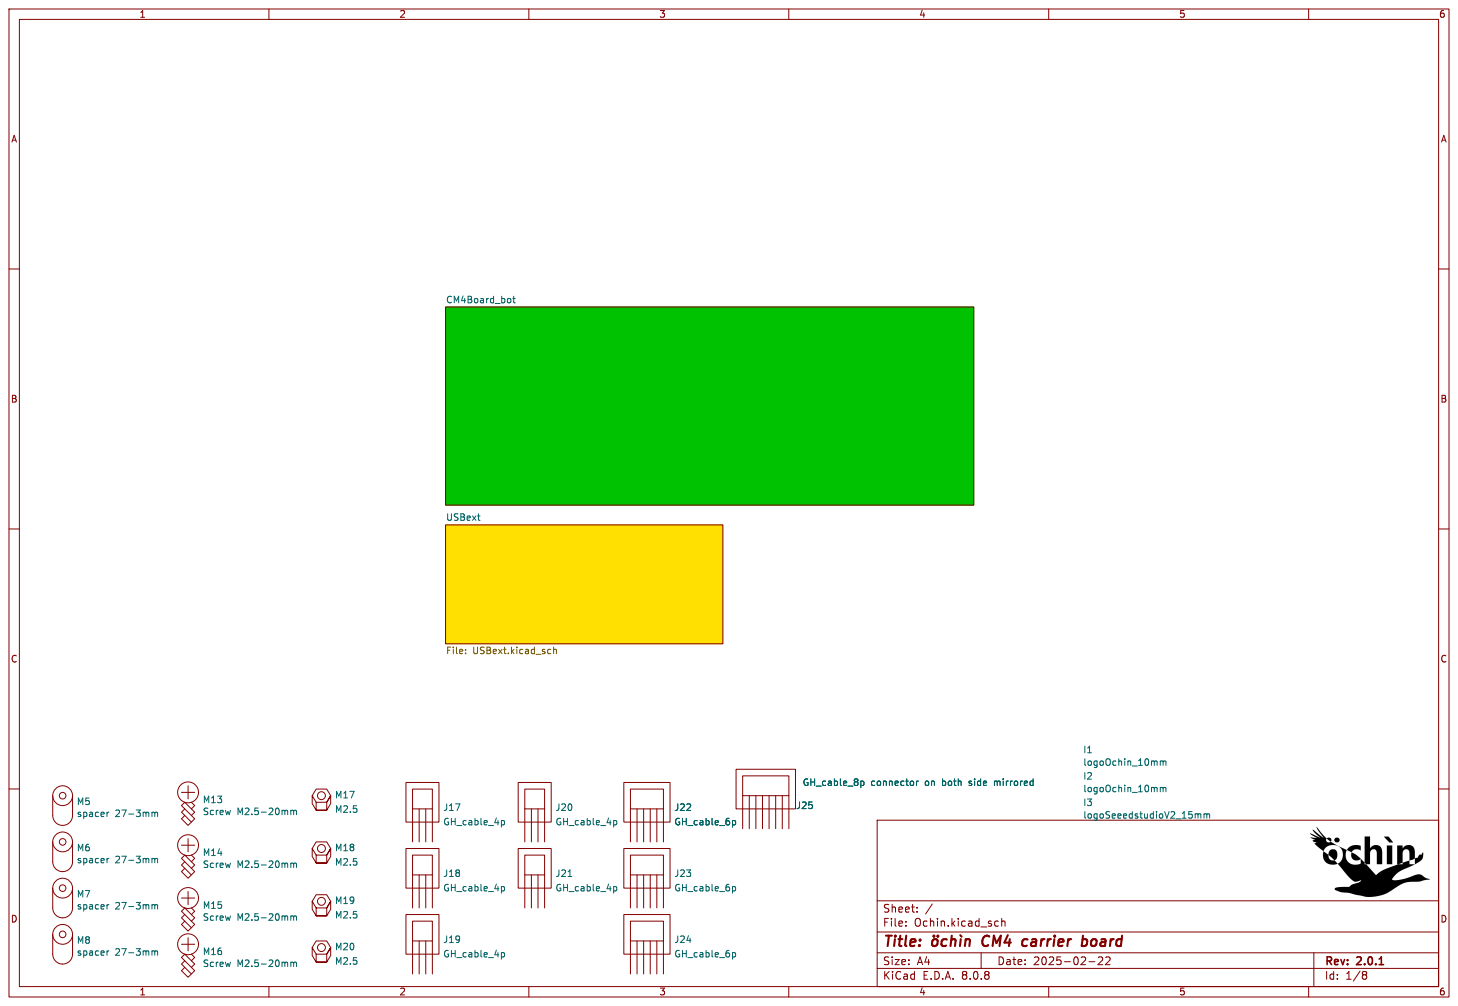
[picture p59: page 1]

File: Ochin.kicad_sch Sheet: /
Id: 1/8 Title: þÿöchìn CM4 carrier board

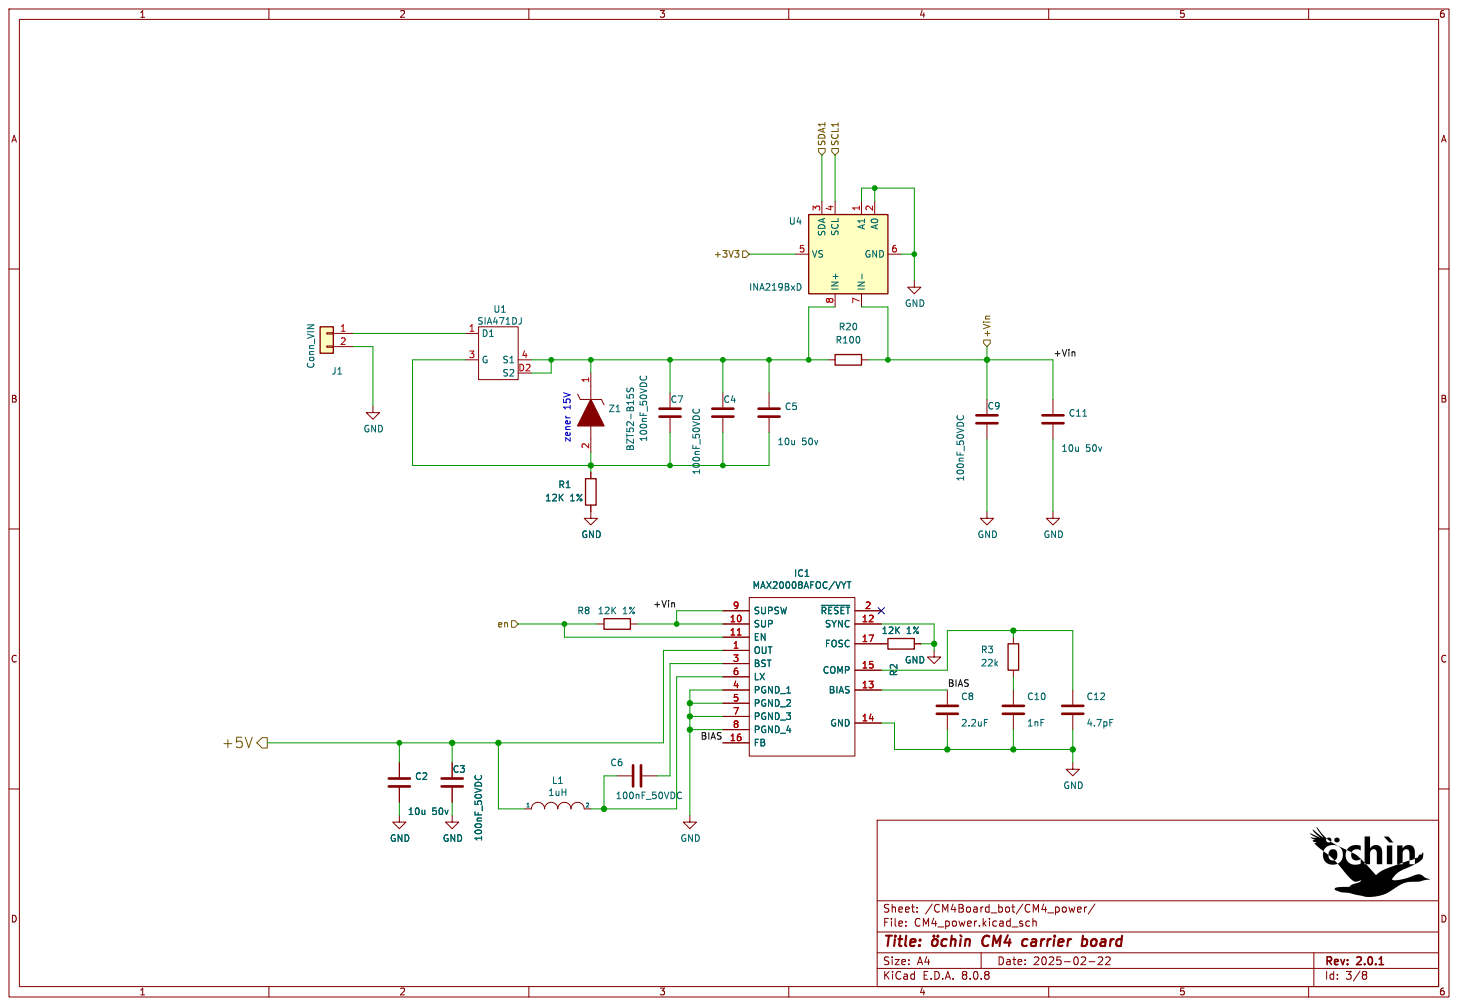
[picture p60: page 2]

Id: 3/8 Title: þÿöchìn CM4 carrier board

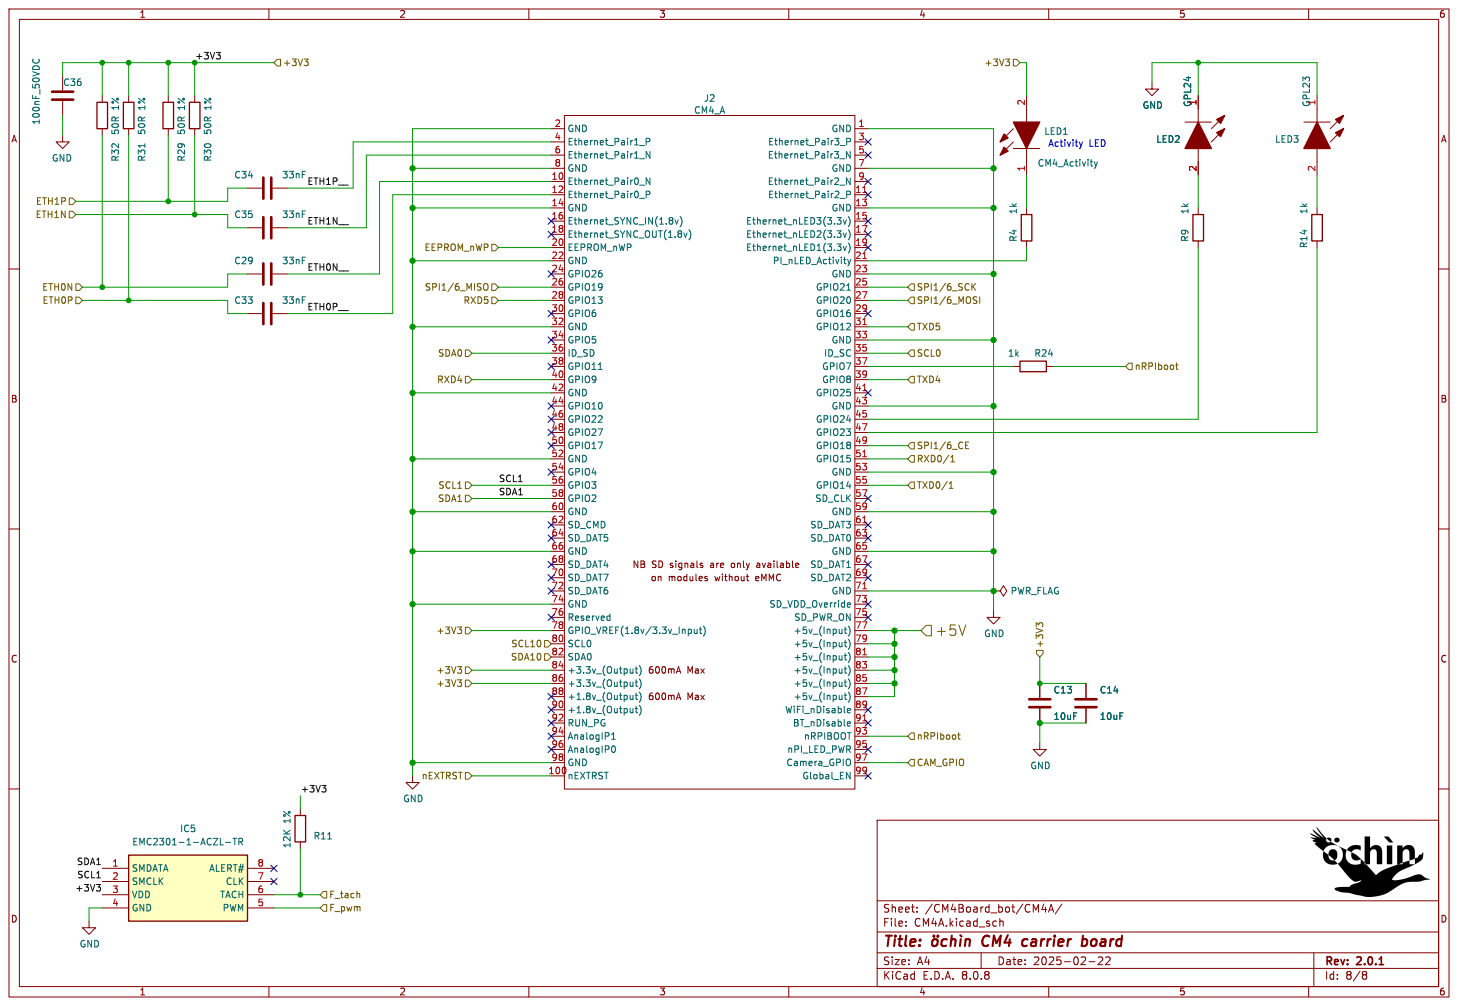
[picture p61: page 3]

600mA Max 600mA Max NB SD signals are only available

File: CM4A.kicad_sch Sheet: /CM4Board_bot/CM4A/
Id: 8/8 Title: þÿöchìn CM4 carrier board

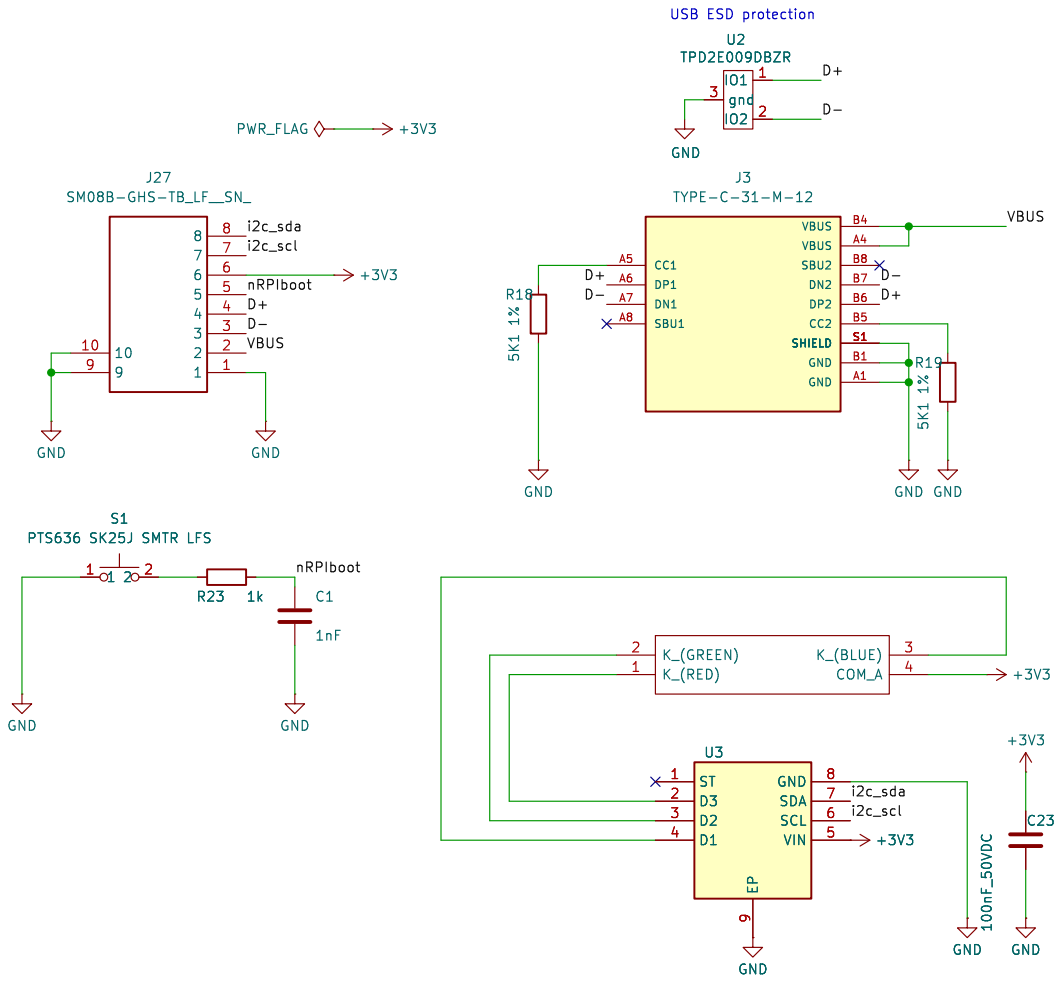
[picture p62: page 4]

File: USBext.kicad_sch Sheet: /USBext/
Id: 8/8 Title: þÿöchìn CM4 carrier board

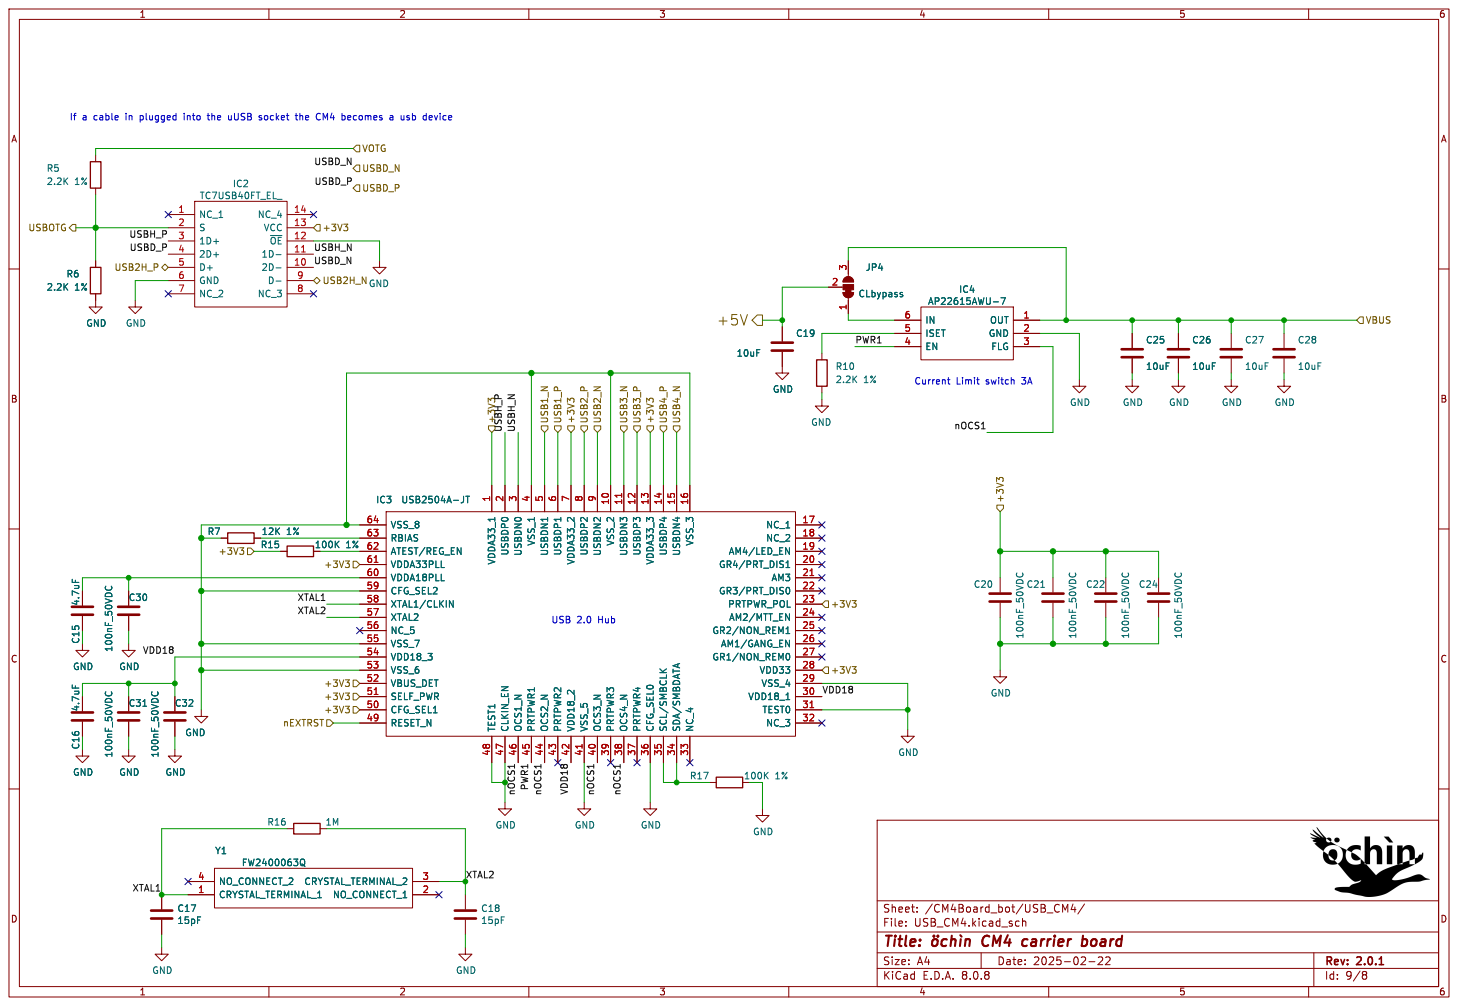
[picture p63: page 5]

3 VDD18_1 30 TEST0 31 NC_3 32 NC_4 33 SDA/SMBDATA 34 SCL/SMBCLK 35 CFG_SEL0 36 PRTPWR4 37 OCS4_N 38 PRTPWR3 39 VSS_1

Id: 9/8 Title: þÿöchìn CM4 carrier board

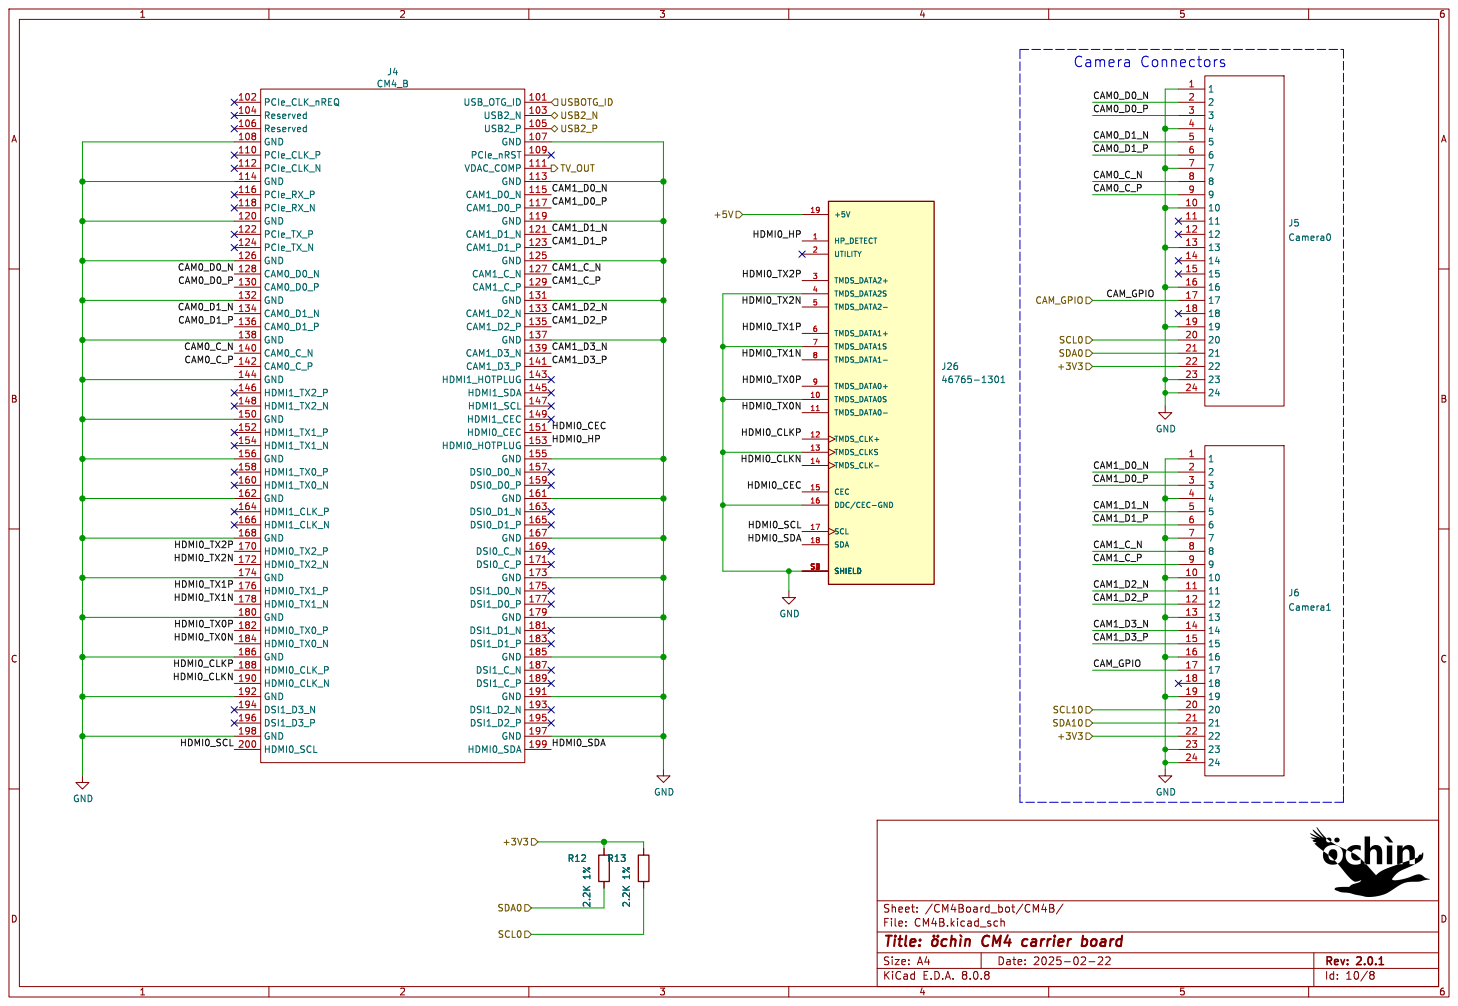
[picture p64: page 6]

Id: 10/8 Title: þÿöchìn CM4 carrier board

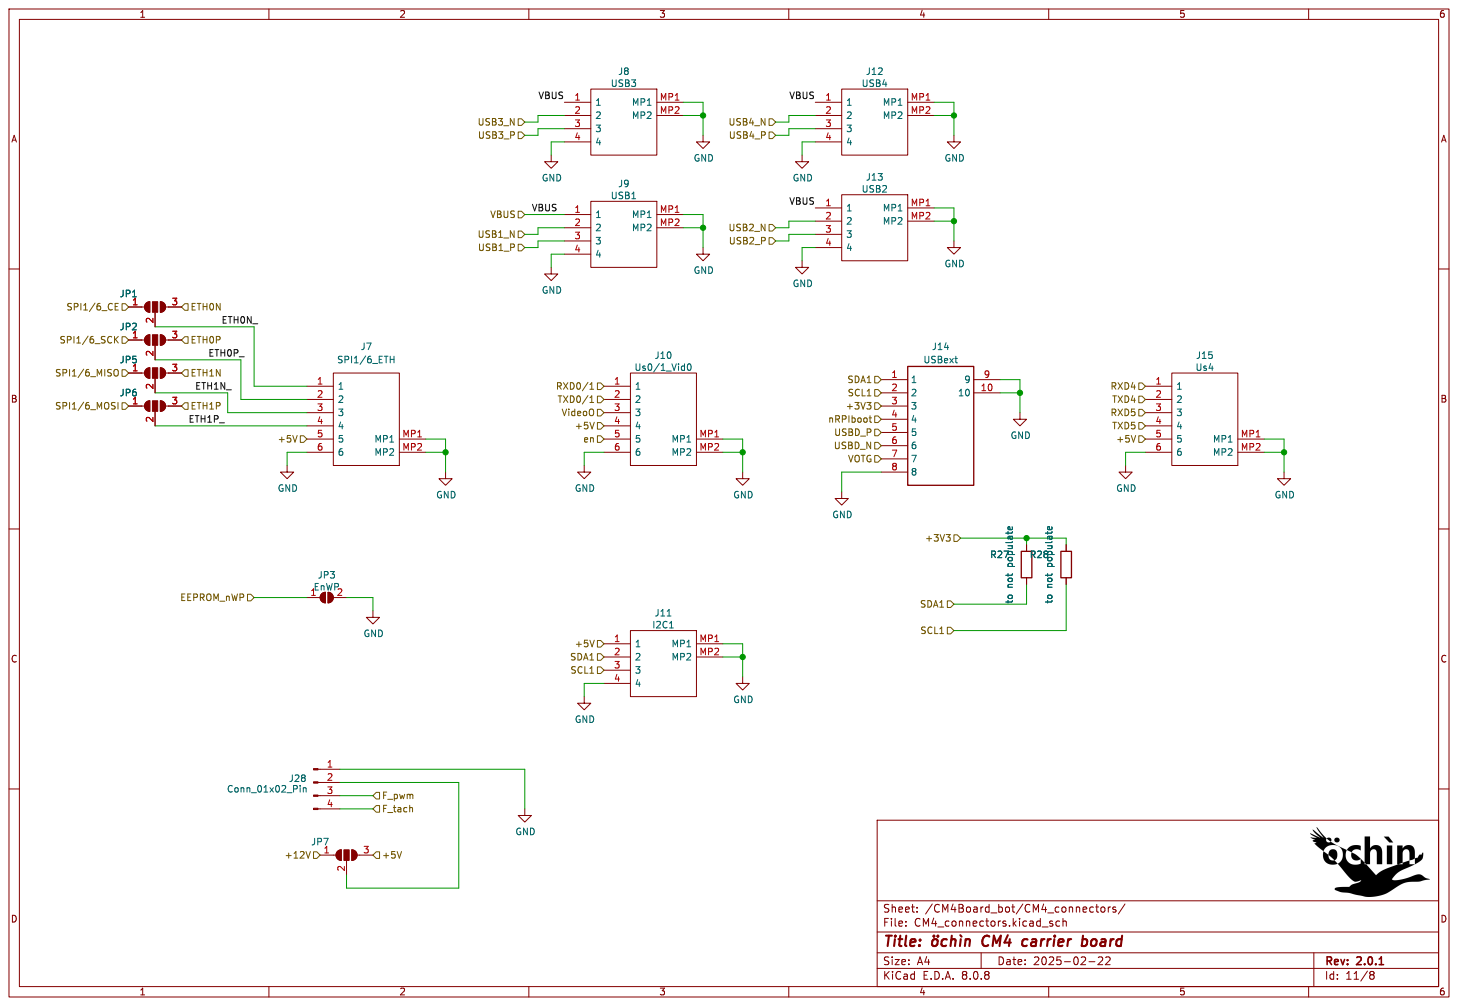
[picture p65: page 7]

File: CM4_connectors.kicad_sch Sheet: /CM4Board_bot/CM4_connectors/
Id: 11/8 Title: þÿöchìn CM4 carrier board

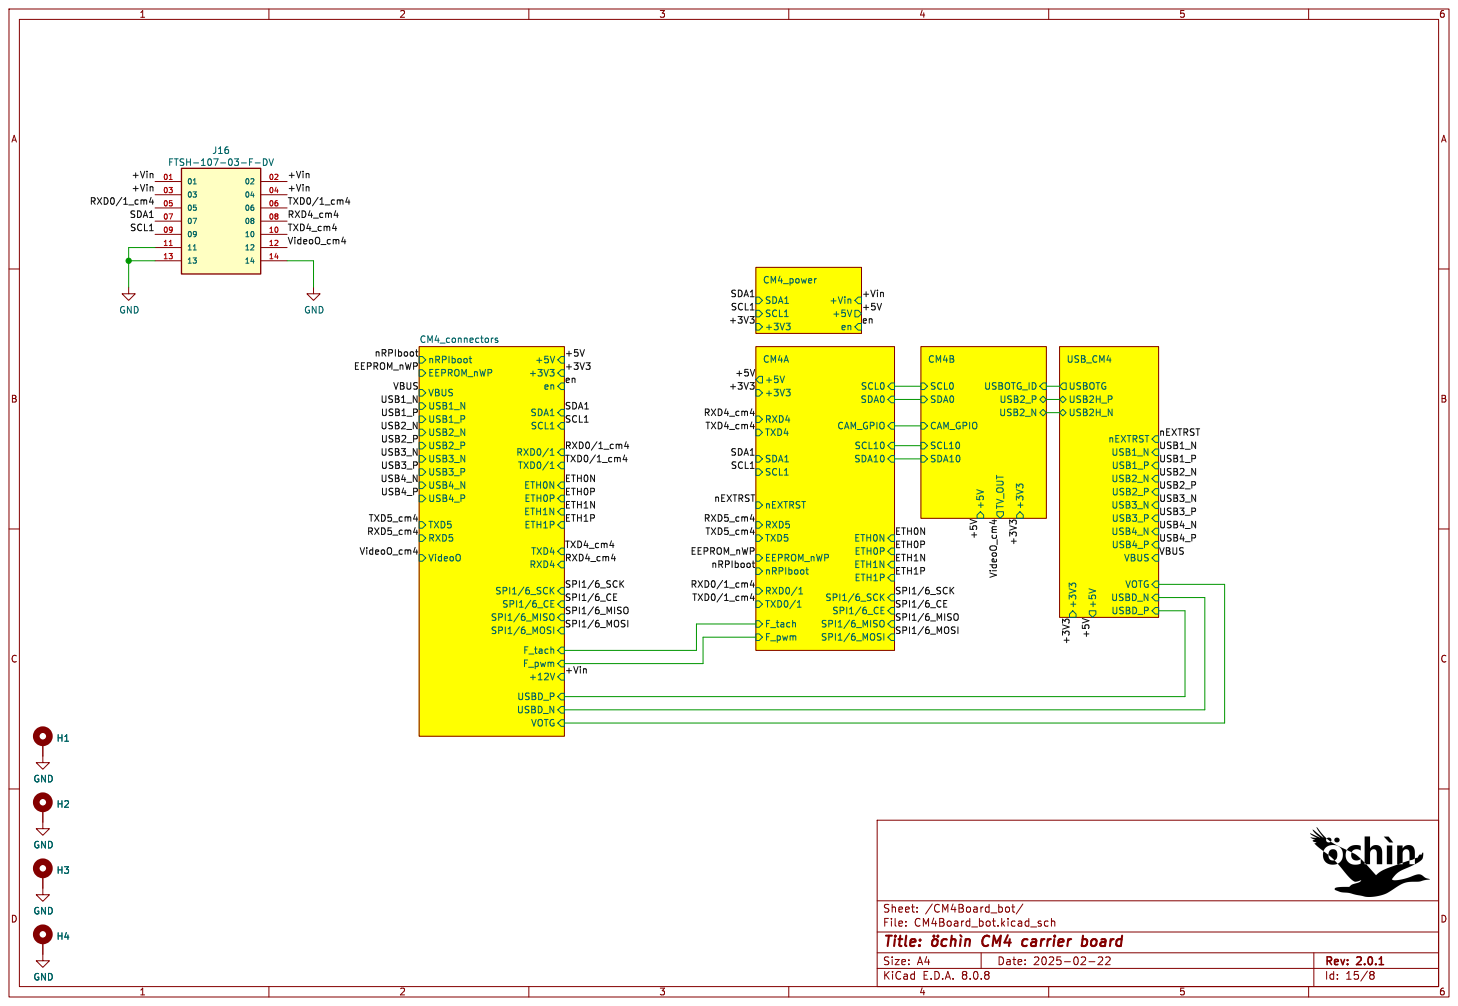
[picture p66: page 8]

File: CM4Board_bot.kicad_sch Sheet: /CM4Board_bot/
Id: 15/8 Title: þÿöchìn CM4 carrier board

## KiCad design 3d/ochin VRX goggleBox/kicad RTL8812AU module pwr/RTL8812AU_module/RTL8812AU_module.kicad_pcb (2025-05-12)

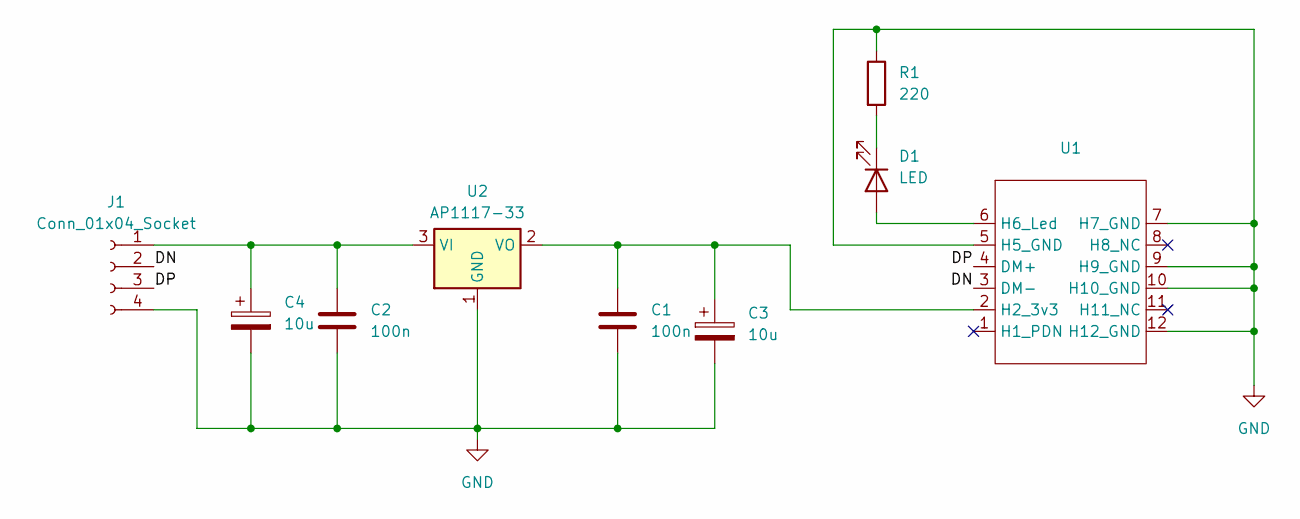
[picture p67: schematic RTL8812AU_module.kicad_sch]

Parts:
C1, C2: 100n; C_0805_2012Metric_Pad1.18x1.45mm_HandSolder
C3, C4: 10u; CP_EIA-3216-10_Kemet-I_Pad1.58x1.35mm_HandSolder
D1: LED; LED_0805_2012Metric_Pad1.15x1.40mm_HandSolder
J1: Conn_01x04_Socket; PinHeader_1x04_P2.54mm_Vertical
R1: 220; R_0805_2012Metric_Pad1.20x1.40mm_HandSolder
U1: RTL8812AU
U2: AP1117-33; SOT-223-3_TabPin2

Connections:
/DN: J1.2, U1.3 (DM-)
/DP: J1.3, U1.4 (DM+)
GND: C1.2, C2.2, C3.2, C4.2, J1.4, R1.1, U1.5 (H5_GND), U1.7 (H7_GND), U1.9 (H9_GND), U1.10 (H10_GND), U1.12 (H12_GND), U2.1 (GND)
unnamed: D1.2 (A), U1.6 (H6_Led)
unnamed: D1.1 (K), R1.2
unnamed: C2.1, C4.1, J1.1, U2.3 (VI)
unnamed: C1.1, C3.1, U1.2 (H2_3v3), U2.2 (VO)

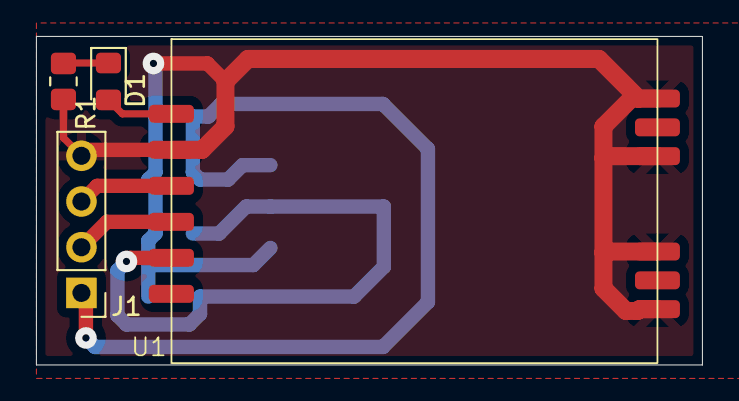
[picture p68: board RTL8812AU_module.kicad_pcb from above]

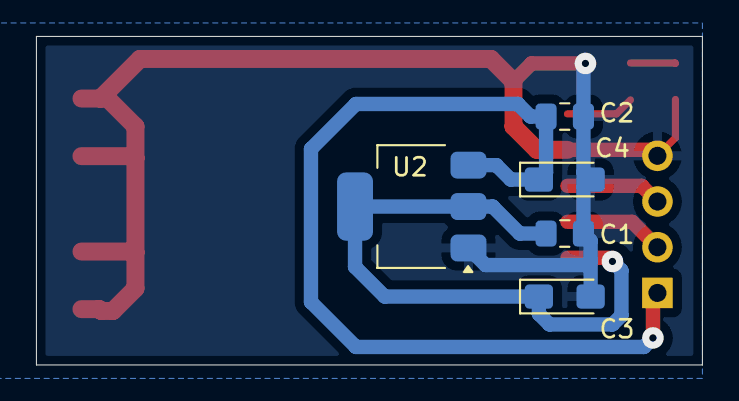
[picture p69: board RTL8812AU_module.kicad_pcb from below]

Board: 2 copper layers, 37.0 x 18.2 mm, 9 parts (5 on the bottom side), 7 nets.

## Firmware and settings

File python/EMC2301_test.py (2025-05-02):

#sudo apt-get install python3-smbus
#dtparam=i2c_arm=on,i2c_arm_baudrate=400000
from smbus import SMBus
import time

i2cbus = SMBus(1)  # Create a new I2C bus
EMC2301_ADDRESS = 0x2f
Fan1Setting = 0x30
TACH_LSB_REG = 0x3E  # Reg LSB
TACH_MSB_REG = 0x3F  # Reg MSB

def count2RPM(count):
    EDGES_PER_REV = 2
    rpm = 3932160*2/count
    return rpm

def readTacho():
    lsb = i2cbus.read_byte_data(EMC2301_ADDRESS, TACH_LSB_REG)
    msb = i2cbus.read_byte_data(EMC2301_ADDRESS, TACH_MSB_REG)
    tach_count = (msb << 8) | lsb
    return count2RPM(tach_count)

def main():
    
    i2cbus.write_byte_data(EMC2301_ADDRESS, Fan1Setting, 0x00)
    time.sleep(4)   
    print("tacho: "+"%.2f" % readTacho())
    i2cbus.write_byte_data(EMC2301_ADDRESS, Fan1Setting, 0x64)
    time.sleep(4)
    print("tacho: "+"%.2f" % readTacho())
    i2cbus.write_byte_data(EMC2301_ADDRESS, Fan1Setting, 0xff)
    time.sleep(4)
    print("tacho: "+"%.2f" % readTacho())
    i2cbus.write_byte_data(EMC2301_ADDRESS, Fan1Setting, 0x64)
    time.sleep(4)
    print("tacho: "+"%.2f" % readTacho())


if __name__ == "__main__":
    main()

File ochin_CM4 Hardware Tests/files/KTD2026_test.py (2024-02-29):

#sudo apt-get install python3-smbus
#dtparam=i2c_arm=on,i2c_arm_baudrate=400000
from smbus import SMBus
import time

def main():
	# Define registers values from datasheet
	ENRST = 0x00  # 
	FlashPer1 = 0x01  # 
	FlashOn1 = 0x02  #
	FlashOn2 = 0x03  #
	ChCTRL = 0x04  #
	RampRate = 0x05  #ramp-up/down transitions from 0% to 100%
	Led1Iout = 0x06  #1 led brightness
	Led2Iout = 0x07  #2 led brightness
	Led3Iout = 0x08  #3 led brightness
	Led4Iout = 0x09  #4 led brightness(for KTD2027)

	i2cbus = SMBus(1)  # Create a new I2C bus
	time.sleep(1)
	i2caddress = 0x32  # Address of KTD2026 device

    try:
        #ENRSTstat = i2cbus.read_byte_data(i2caddress, ENRST)  # Read ENRST
        #print(ENRSTstat) # print the value ENRST
        ENRSTstat = i2cbus.write_byte_data(i2caddress, ENRST, 0x07)  # chip reset  
        print("chip reset done") 
	except:
        print("chip reset failed")  
	time.sleep(0.5)
	i2cbus.write_byte_data(i2caddress, ChCTRL, 0x15) #led 1,2,3 ON  
    print("LEDs 1,2,3 always on") 
    
	#i2cbus.write_byte_data(i2caddress, FlashPer1, 0x8e) #Flash period 1.92sec, linear rate
	#i2cbus.write_byte_data(i2caddress, FlashOn1, 0x50) #ON Timer1 %
	#i2cbus.write_byte_data(i2caddress, FlashOn2, 0x32) #ON Timer2 %
	#i2cbus.write_byte_data(i2caddress, ChCTRL, 0x2a) #led 1,2,3 Tim1 
	#i2cbus.write_byte_data(i2caddress, RampRate, 0x11) #ramp rate 1x, 128ms rise/fall time
    
    print("Blue") 
	i2cbus.write_byte_data(i2caddress, Led1Iout, 0xff)
	i2cbus.write_byte_data(i2caddress, Led2Iout, 0x00)
	i2cbus.write_byte_data(i2caddress, Led3Iout, 0x00)
	time.sleep(2)
    print("Green") 
	i2cbus.write_byte_data(i2caddress, Led1Iout, 0x00)
	i2cbus.write_byte_data(i2caddress, Led2Iout, 0xff)
	i2cbus.write_byte_data(i2caddress, Led3Iout, 0x00)
	time.sleep(2)
    print("Red") 
	i2cbus.write_byte_data(i2caddress, Led1Iout, 0x00)
	i2cbus.write_byte_data(i2caddress, Led2Iout, 0x00)
	i2cbus.write_byte_data(i2caddress, Led3Iout, 0xff)
	time.sleep(2)

	while (True):
        for b in range(0,50,5):
            for g in range(0,50,5):
                for r in range(0,50,5):
                    i2cbus.write_block_data(i2caddress, Led1Iout, [b, g, r])
                    time.sleep(0.001)
        for b in range(0,50,5):
            for g in range(0,50,5):
                for r in range(0,50,5):
                    i2cbus.write_block_data(i2caddress, Led1Iout, [50-b, 50-g, 50-r])
                    time.sleep(0.001)
                    
if __name__ == "__main__":
    main()

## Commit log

2023-08-27 first commit for the ochin_CM4v2
    [EasyStar_camera_mount.FCStd, EasyStar_camera_mount_bridge.stl, EasyStar_camera_mount_cap.stl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]
2024-02-12 updated docs for v2
    [config.txt, osdconfig.txt]
2024-02-12 updated 3d files
    [ochin_CM4.stl, ochin_CM4v2.stl, ochin_CM4v2_ext.stl]
2024-11-25 added HW buglist file updated README.md
    [ochin_mount-botCover.stl, ochin_mount-extractor.stl, ochin_mount-topCover.stl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]
2025-01-09 -updated the schematic of V2.0.1 -updated HW bugs list
2025-05-02 updated docs for v2.0.1
    [Ochin_CM4_V2_0_1_ext.stl, ochin_CM4v2.stl, ochin_CM4v2_ext.stl]
2025-05-12 added VRX goggleBox
    [Bot.stl, RTL8812AU_module.kicad_pcb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]
